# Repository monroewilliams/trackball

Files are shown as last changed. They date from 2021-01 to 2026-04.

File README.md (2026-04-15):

This is the code to run a trackball I'm building for myself.<br>

It's currently based around either a [Seeeduino XIAO](https://wiki.seeedstudio.com/Seeeduino-XIAO/) or the very similar [Adafruit QT Py](https://www.adafruit.com/product/4600), and a couple of optical mouse sensor breakout boards. I've built two so far, one using [these ADNS-9800 boards](https://www.tindie.com/products/jkicklighter/adns-9800-optical-laser-sensor/), and one using [these PMW3360 breakout boards](https://www.tindie.com/products/jkicklighter/pmw3360-motion-sensor/).

### Update January 2025 ###
As an alternative to off-the-shelf microcontrollers and sensor boards, I've created a custom main board and sensor breakouts that can be ordered from a PCB creation/assembly service (I've been using [JLCPCB](https://jlcpcb.com)). The KiCad files and the files need to order them from JLCPCB are in their own repositories on github. 

[Details on the custom boards are here.](hardware/Custom.md)

### Update January 2026 ###
I've refined the model for the main body of the trackball to be less of a brick and more of a hollow shell, which leaves much more room inside for wire routing, etc. The cable outlet at the front of the shell now also provides an option for a hard-mounted [usb-c plug](https://www.sparkfun.com/sparkfun-usb-c-breakout.html), or [similar](https://www.amazon.com/dp/B0CB2VFJ54) [clones](https://www.aliexpress.us/item/3256808121945210.html) 

I added an [updated version of the button carrier](hardware/Button-carrier-v2.md). Its design is a bit more refined overall, but the main feature is that it allows you to avoid soldering wires to the microswitch by accepting a 3-pin JST XH female connector.

I also added an option to modify the sensor transform for a left-handed build. To make use of this, print mirrored versions of the main body and bottom plate (most slicers have an option to do this at slicing time), and define LEFT_HANDED when compiling trackball.cpp to modify the sensor transform. The `env:rp2040_mwtrackball_left_handed` section in [platformio.ini](platformio.ini) demonstrates this.

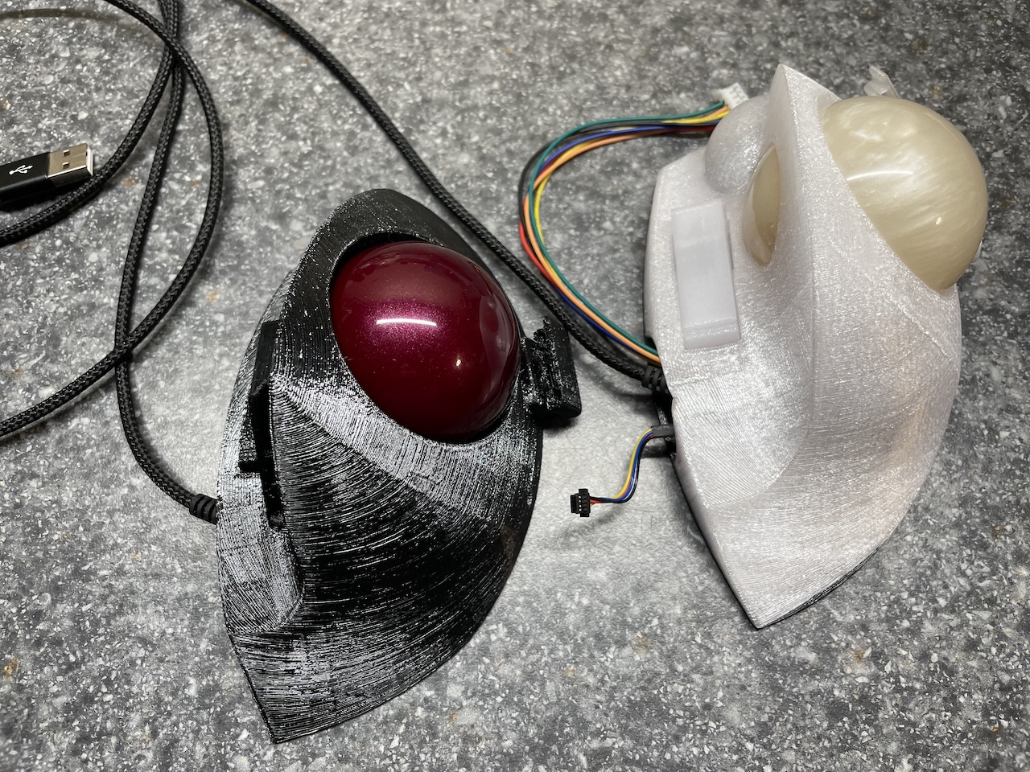
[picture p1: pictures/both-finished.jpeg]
<br>

## History ##

I started this project because my favorite ergonomic trackball, the Trackman Marble FX, is basically no longer viable. I really like the shape of it, but it's PS/2 only, has a number of issues with tracking and durability, and has become really hard to find/expensive. I have a small collection of them, most of which have broken over the years.<br>

I decided to build my own trackball with a shape that fits my hand similar to the old Trackman Marble FX, and incorporated a feature from the Kensington Slimblade (probably my second favorite, although not for its ergonomics): twisting the ball in the Z axis acts like a scroll-wheel (complete with clicky sounds produced by a piezo speaker).<br>

[Short video demo is here](https://www.youtube.com/watch?v=PVdwrbiuzwA)

To be able to sense rotation in all three axes, it needs to use two mouse sensors, positioned at different points around the ball. <br>

I'm quite happy with the current state of the project. I prefer using this trackball to any other I've used at this point, which is saying something. :) <br>

The [hardware](hardware) directory contains the OpenSCAD files for the printed plastics. The [src](src) directory has the code. If you want to see how all the parts fit together, you can go straight to the [assembly guide](hardware/Assembly.md). <br>

## BUILD ##

I'm building this with PlatformIO/VSCode. The root of the repository should open directly with VSCode.

I do my work on Mac OS X, so I don't know if there will be any issues using it on Windows or Linux.

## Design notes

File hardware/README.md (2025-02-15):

# Printables #

This directory contains the [OpenSCAD](https://www.openscad.org) models for the trackball body and microswitch buttons I've designed.

The trackball body model is in `trackball.scad`. There are many parameters that can be tweaked, see the comments in that file for details. 

It's designed using 14mm square holes for the buttons, which should fit either standard Cherry MX (or compatible) keyboard switches or the microswitch-based button I've designed for the project.

The model for the button is in `microswitch-cherry-mx.scad`. The variables at the top set front and rear overhangs, which can match up with cutouts in the trackball body to act as recessed buttons with minimal travel.

If you're thinking about putting one together yourself, take a look at the [assembly guide](Assembly.md).

# Components #

In addition to the 3D printed parts, you will need the following:

## Microcontroller ##

I've used all of the following:

- Seeeduino XIAO microcontroller (although any controller that has a binding for the Arduino library in PlatformIO should be easy to adapt):

https://wiki.seeedstudio.com/Seeeduino-XIAO/

- Adafruit QT Py (it's very similar with the same pinout and processor). It has a couple of niceties over the XIAO, including an actual reset button and an RGB LED that could be used to light things up.

https://www.adafruit.com/product/4600

- Adafruit QT Py RP2040, which is a somewhat more capable processor:

https://www.adafruit.com/product/4900

- [My custom board](./Custom.md), which can be assembled for you by an assembly service like [JLCPCB](https://jlcpcb.com).

## Optical mouse sensors ##

You will need two of these. I originally started this project with ADNS-9800 laser optical mouse sensor breakouts from here:

https://www.tindie.com/products/jkicklighter/adns-9800-optical-laser-sensor/

and have since picked up two PMW3360 optical mouse sensor breakouts from here:

https://www.tindie.com/products/jkicklighter/pmw3360-motion-sensor/

The plastics have options to use either kind (or even one of each), and the code also supports both kinds.

The PMW3389 breakout from the same source should also work.

https://www.tindie.com/products/jkicklighter/pmw3389-motion-sensor/

It seems that this seller is no longer active, but other sellers on Tindie have similar products:

https://www.tindie.com/products/citizenjoe/pmw3360-motion-sensor/

https://www.tindie.com/products/citizenjoe/pmw3389-motion-sensor/

I also have a [custom-designed sensor board](./Custom.md) that pairs well with my custom main board, and can also be ordered from [JLCPCB](https://jlcpcb.com).

## Ball ##

My original prototype used a regulation 2 1/4" (~57mm) billiard ball. The ADNS-9800 sensors I was using at the time really wanted some optical texture to be able to track the ball, and the best one I found was the cue ball from a pearlescent set I bought from eBay just for this project.

The set I bought: https://www.ozonebilliards.com/product/pro-series-kandy-pearl-ball-set

Similar single cue ball: https://www.paramountindustriesinc.com/products/pearlescent-cue-ball

For best results with modern sensors like the PMW3360/3380, I would highly recommend using a 55mm ball specfically designed for an optical trackball. These have a sort of "sparkly" visual texture that works really well with the optical sensors. This ball will fit and work fine in a body printed with a ball diameter of 57mm, but I would recommend bumping ball_diameter down to 55 in trackball.scad for a better fit.

The Kensington Slimblade and Kensington Expert Mouse trackballs use this size, as does the Perixx Periboard combination keyboard/trackball. Perixx sells a compatible replacement ball, which is a good way to get one without buying extra hardware you don't need:

https://www.amazon.com/gp/product/B07DXBMT6Z/

and various sellers on Amazon and AliExpress have similar 55mm replacement balls:

https://www.amazon.com/gp/product/B0CPDG8LX4

https://www.aliexpress.us/item/3256806116943772.html (Careful with this one -- it's easy to order the 34mm ball by mistake.)

## USB Cable ##

You'll neeed a USB-C cable with a relatively small connector. There's not a lot of room under the printed shell for the cable plug.

I've modeled a channel for the cable to run out the front of the body, but I haven't yet found a cable that can plug into the microcontroller and make the turn to get into the channel, which is why the cable currently sticks out the side. I may eventually switch to a processor that has solder-pads for the USB connection, or hack together a cable with a solder-on USB-C plug, but for now I'm using one of these:

https://www.amazon.com/gp/product/B081F1VR6W/

## Breadboard ##

Standard mini breadboard (170 tie point version), available through many sources:

https://www.amazon.com/Breadboard-Solderless-Prototype-Different-Raspberry/dp/B07LF71ZTS/

## Bearings ##

You will need 3 ceramic ball bearings, diameter 1/8 inch (3.175mm), which press-fit into holes in the printed body. 
For smooth operation, I recommend grade G5 or better (lower numbers are smoother, so G10 is worse than G5).
They're cheap in packs of 25 or 50, and I recommend getting some extras because they're really easy to lose.
Either of these will work fine:

https://www.amazon.com/gp/product/B081SNH8J5/

https://www.amazon.com/gp/product/B07ZKPZK8Y/

## Buttons ##

Three Subminiature microswitches, OMRON D2FC-F-7N or equivalent (most of the ones sold as "mouse switches" are an idential form factor, approximately 12.8x5.8x6.5mm, and should fit in the carriers):

https://www.amazon.com/D2F-01F-Switch-Microswitch-Subminiature-Logitech/dp/B0062WNDLI

## Piezo speaker ##

If you want twist-scrolling to make a "click" sound, you'll need one of these. (If you don't want this, just undefine PIN_PIEZO in the trackball source and skip it). These are available from multiple sources, I've used one of these:

https://www.adafruit.com/product/160

and also one of these (after desoldering the wires):

https://www.amazon.com/gp/product/B01MR1A4NV/

## Misc ##

4 - M2 x 6mm machine screws to hold the sensors in place. (I originally used some tiny self-tapping screws I had in my junk parts stash, but have since enlarged the screw holes to fit machine screws -- they should hold fine in PETG as long as you don't over-tighten them.)

Hookup wires, solder, etc. for wiring up the sensors and switches. I used some old ribbon cable for the sensor wiring to keep things tidy. I find that soldering the wires to break-apart male header pins makes for solid plug-in attachement to the breadboard.

Optional: Thin adhesive-backed rubber to make non-skid feet for the bottom of the trackball.  I initially used some leftover sticky-backed rubber from a sheet of rubber feet, and later found this stuff, which works much better:

https://www.amazon.com/gp/product/B0D41RLHJZ

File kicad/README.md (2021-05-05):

# Board

This directory contains the [Kicad](https://kicad.org) files for a circuit board I've designed for the trackball. This is intended to take the place of the breadboard in a more permanent build.<br>

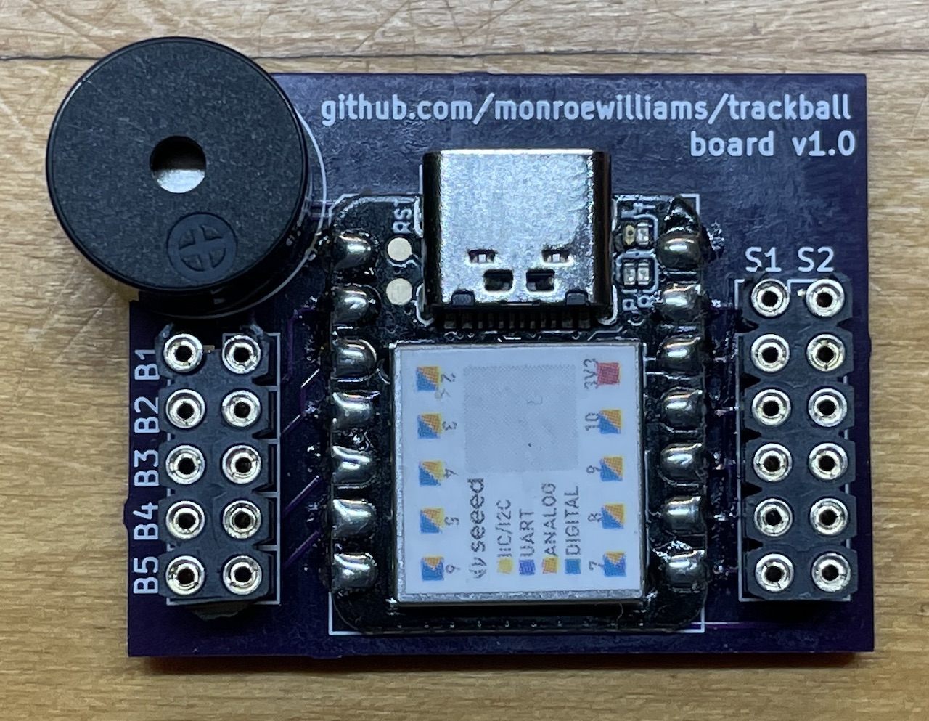
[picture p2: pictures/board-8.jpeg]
<br>

This design uses the [Seeeduino XIAO Kicad library](https://www.seeedstudio.com/blog/2020/04/23/use-seeeduino-xiao-in-kicad-pcb-design-like-a-components/), so if you want to open/modify it with Kicad you probably need to install that first.<br>

This is my first attempt at designing something with Kicad, and I really have no idea what I'm doing. I've had an initial batch of them made by [OshPark](https://oshpark.com), but I haven't actually tested them out yet, so caveat emptor, etc, etc.<br>

I also haven't yet modified the OpenSCAD files for the trackball body to have an option that will make these fit properly. I'm working on that as time allows.<br>

That being said, if you want some of these made for yourself, you can order them 3 at a time [here](https://oshpark.com/shared_projects/D077qVES).<br>

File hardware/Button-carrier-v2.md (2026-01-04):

The updated button carrier prints in two pieces -- the main body, and a cap that holds the microswitch in place.

To use this version, print the `microswitch-v2` stl files instead of the older `microswitch-cherry` ones, insert the microswitch as shown (making sure the switch is oriented with the switch under the projection from the top piece), and snap the cap side in. It should hold the switch tightly when inserted into the square hole in the trackball body.

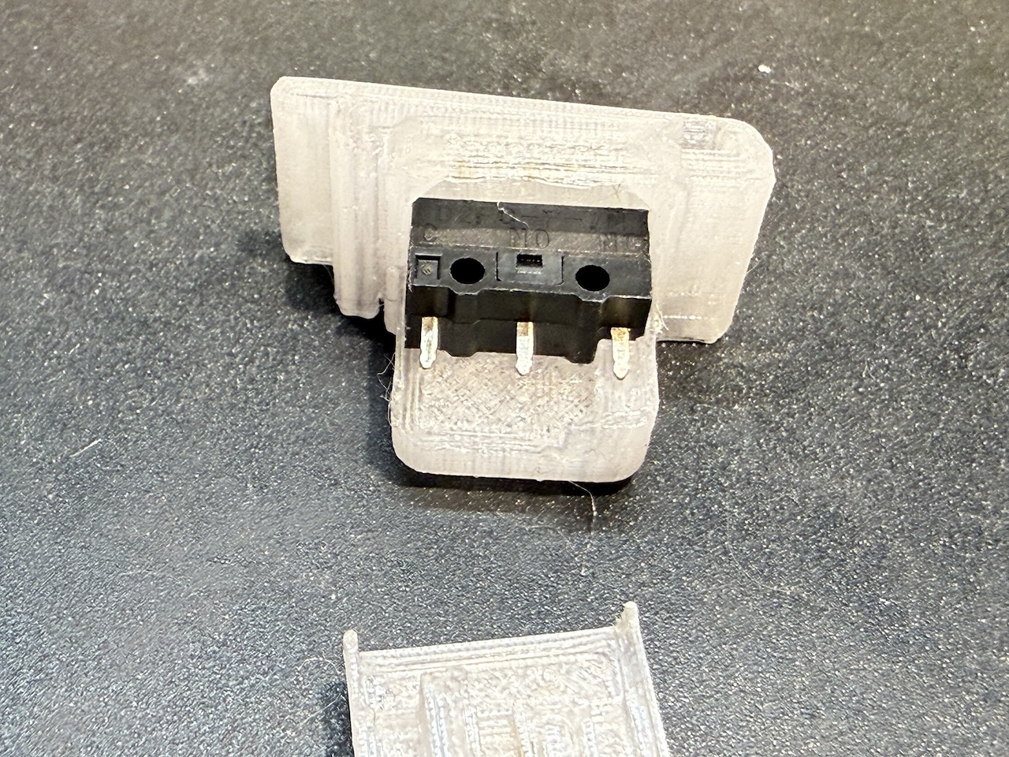
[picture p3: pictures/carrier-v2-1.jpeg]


Insted of soldering wires to the switch, the wiring connection can now be made by inserting a female JST-XH 1.25mm-pitch connector into the back of the carrier. Pins 1 and 3 of the connector will line up with the common and normally-open pins on the microswitch, and the pins on the switch should be close enough to the JST_XH pin profile to make good contact.

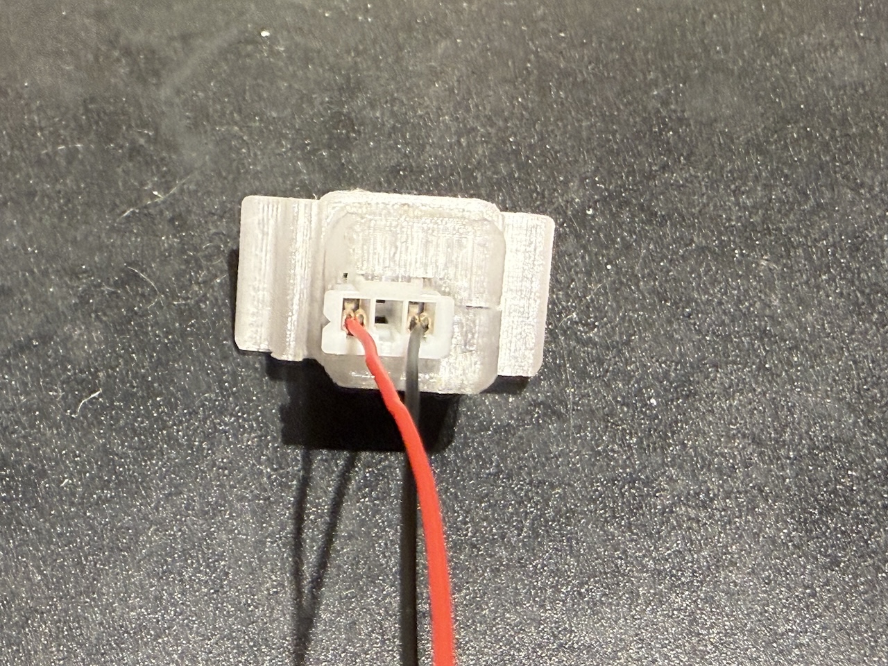
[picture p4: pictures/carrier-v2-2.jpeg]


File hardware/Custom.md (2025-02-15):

# Custom boards #

I recently designed a custom sensor board and main board for use with this trackball design. The primary motivations behind this were:
- more reliable and permanent builds than the original breadboard method
- easier assembly (allowing the use of off-the-shelf cables for the sensors instead of soldering my own)

To this end, both the sensors and the main board use very compact JST-SH 1.0mm pitch connectors (6 pin for the SPI sensors and 2 pin for the buttons). The pinout for the SPI connections on both the mainboard and the sensors is taken from [Pmod Type 2](https://en.wikipedia.org/wiki/Pmod_Interface).

## Sensor breakout ##

My custom sensor board is in [this github repository](https://github.com/monroewilliams/pmw3360-breakout).

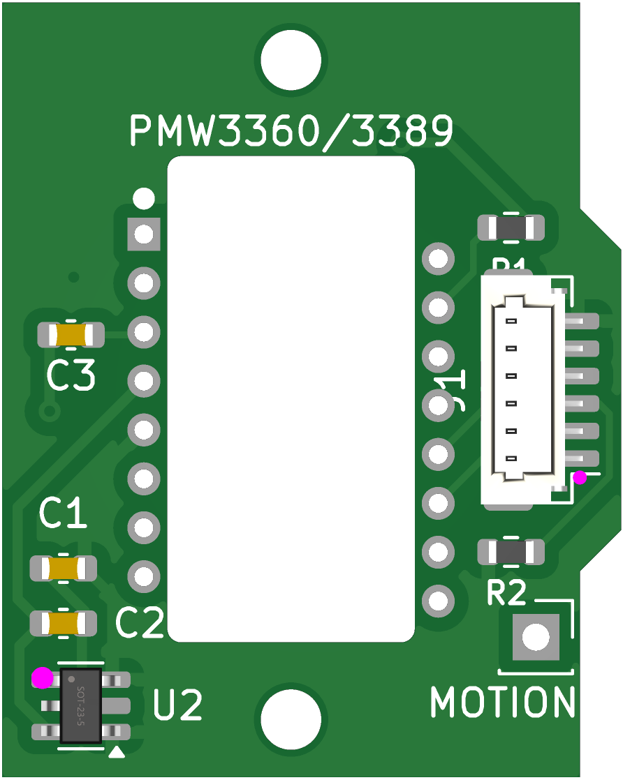
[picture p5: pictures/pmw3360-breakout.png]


It's derived from [jfedor2](https://github.com/jfedor2)'s [PMW3360 breakout board](https://github.com/jfedor2/pmw3360-breakout) project, modified to use a footprint very similar to the PMW3360 breakout boards I sourced from sellers on Tindie, and with a surface mount JST-SH 6 pin connector instead of 2.54mm pitch through-hole pads.

As with his project, there are no level shifters on this board, so it must be used with 3.3v logic. 

The assembly service doesn't seem to be able to place the actual sensor, so I source those separately and hand-solder them (they're through-hole at around 1.75mm pitch, so not too difficult). The board works equally well with PMW3360 and PMW3389 sensors (the pinouts are compatible). Both sensors can be found on AliExpress for under $10USD each, just make sure you order ones that have the "LM19-LSI" lens included, like [this one](https://www.aliexpress.us/item/3256807282468640.html).

## Main board ##

The main board is in [this github repository](https://github.com/monroewilliams/rp2040_mwtrackball).

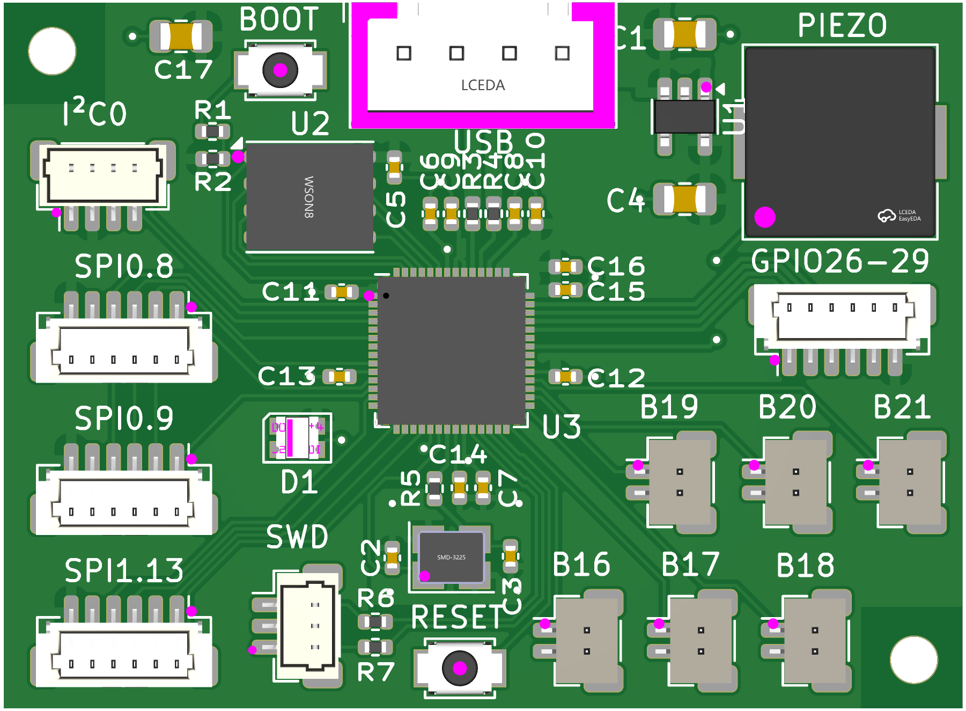
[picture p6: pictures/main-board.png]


It uses an RP2040 processor, and is derived from the sample [minimal reference design](https://datasheets.raspberrypi.com/rp2040/Minimal-KiCAD.zip) provided by Raspberry Pi.

Features include:
- 2 JST-SH 6 pin connectors connected to SPI0, with distinct chip-select lines
- 1 JST-SH 6 pin connector connected to SPI1, with its own chip-select line
- 6 JST-SH 2 pin connectors each connected to a GPIO (16 through 21) and ground, for easy connection to button switches
- 1 JST-SH 4 pin connector connected to I2C-capable pins, and compatible with Qt-STEMMA plugs
- 1 JST-SH 3 pin connector following the [Raspberry Pi 3-pin Debug Connector Specification](https://datasheets.raspberrypi.com/debug/debug-connector-specification.pdf)
- 1 JST-SH 6 pin connector breaking out some of the remaining GPIOs (26 through 29), as well as +3.3v and ground
- USB broken out on a 4 pin JST-XH header.
- an on-board surface mount piezo speaker
- a NeoPixel LED (because why not?)

For the basic trackball design, all that's needed is two of the SPI connections and 3 buttons (give or take), but if I was going to the trouble of designing a board I wanted to give it a bit of room to grow. 

The overall dimensions of the board (46mm x 34mm) are approximately the same as those of the mini-breadboard I used in the original project. This means it will fit in the existing plastics design without any modifications. (Although if you're replacing the electronics in an existing build like I did, the new sensor boards may need a bit more clearance. A hand file is your friend here.)

This repository has a variants directory containing a [pins_arduino.h](../variants/rp2040_mwtrackball/pins_arduino.h) describing the board, and there's an `[env:rp2040_mwtrackball]` section in the [platformio.ini](../platformio.ini) showing how to use it. This is the configuration I'm currently using for my own trackball, so I can say with some confidence that it works.

## Cables, etc. ##

I was able to source all the cables I needed for assembly pretty cheaply from AliExpress. 

Both types of JST-SH cables I used are from [here](https://www.aliexpress.us/item/3256807031812901.html) 
- "6P, 100mm, Reverse" for the SPI cables
- "2P, 100mm, Single head" for the pigtail cables to connect the button switches (I just hand-soldered these to the switch contacts)

The USB cable [here](https://www.aliexpress.us/item/3256806154142780.html) ("XH2.54-4P 1M") has the correct pinout to plug directly into the JST-XH USB header.

## Assembled ##

These are pictures of a board from the second prototype run, before I added the SWD plug. The first batch of "version 1.0" boards is in production as I write this.

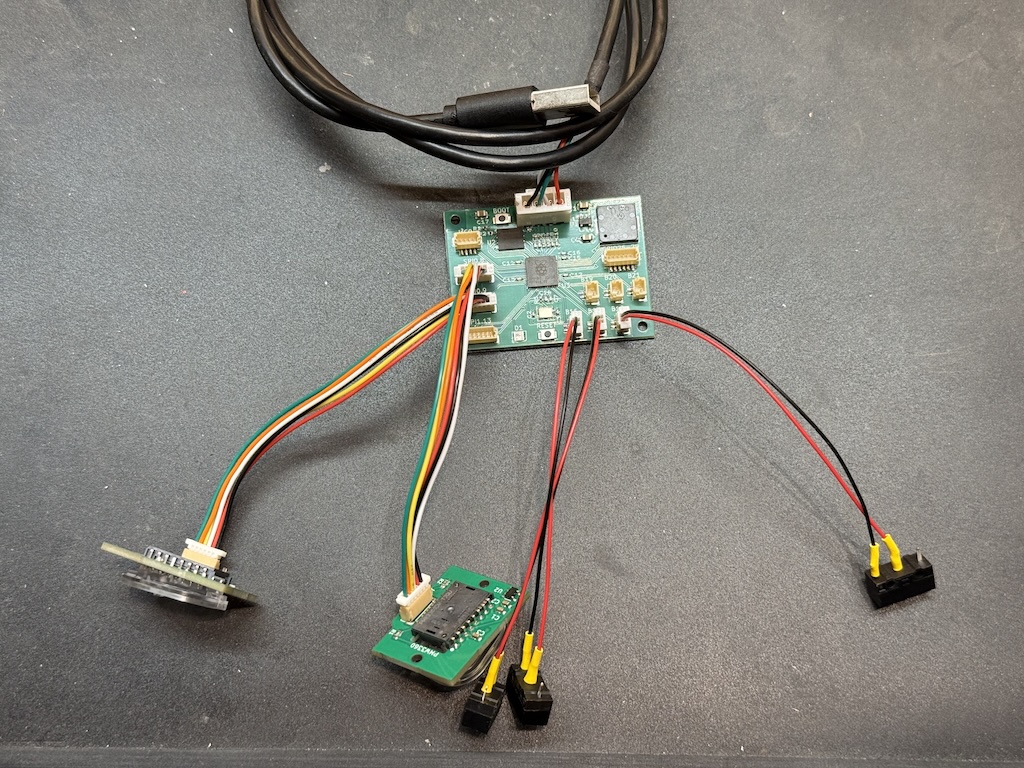
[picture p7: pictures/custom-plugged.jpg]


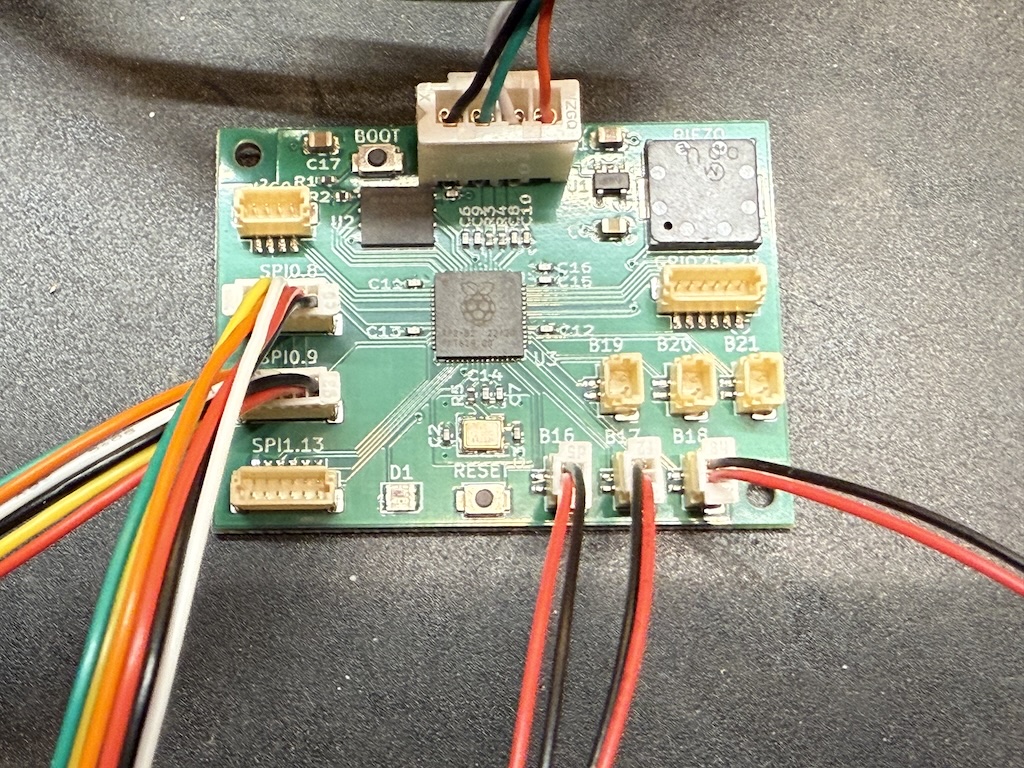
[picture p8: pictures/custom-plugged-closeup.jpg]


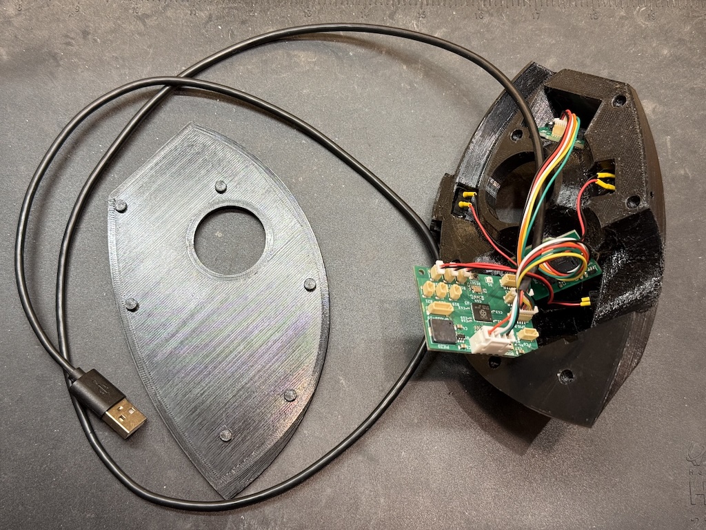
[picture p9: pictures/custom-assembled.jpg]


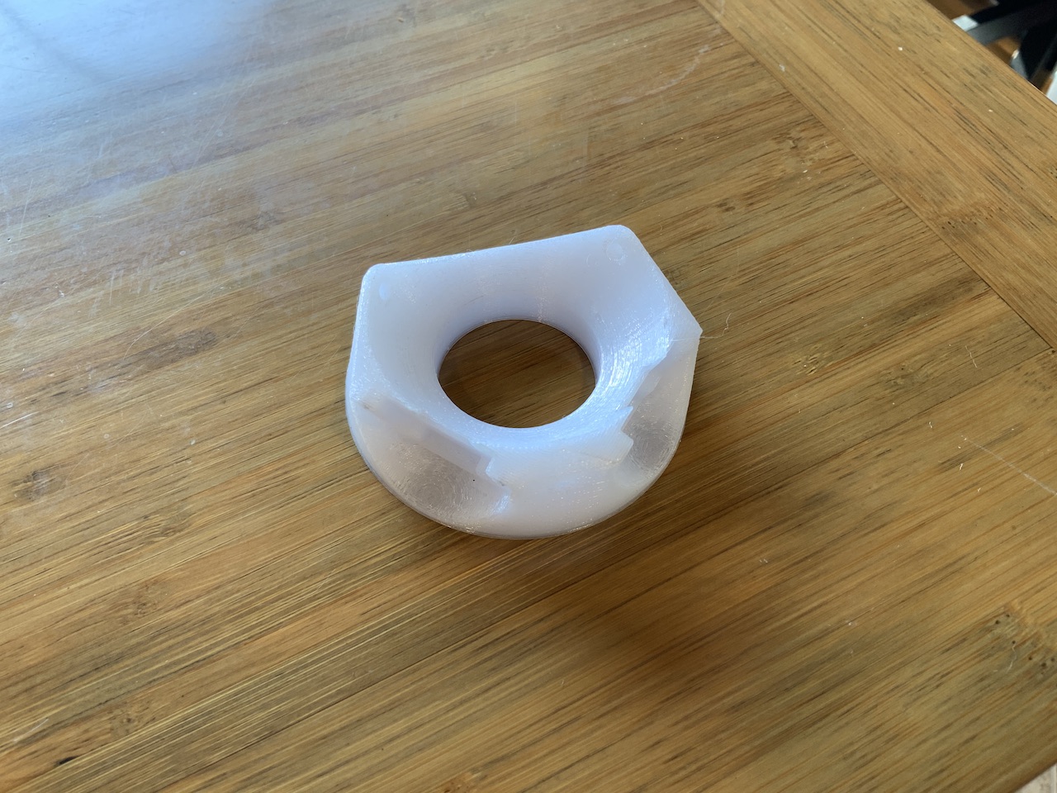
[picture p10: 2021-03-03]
pictures/prototype-2.jpeg

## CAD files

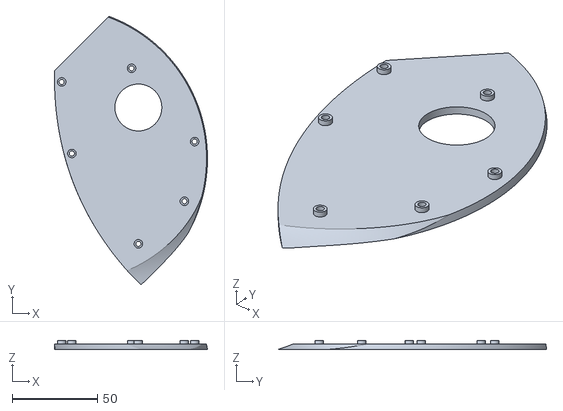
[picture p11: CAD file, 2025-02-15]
stl/bottom_cover_3mm-52.5mm.stl
89.8 x 157.4 x 5.00

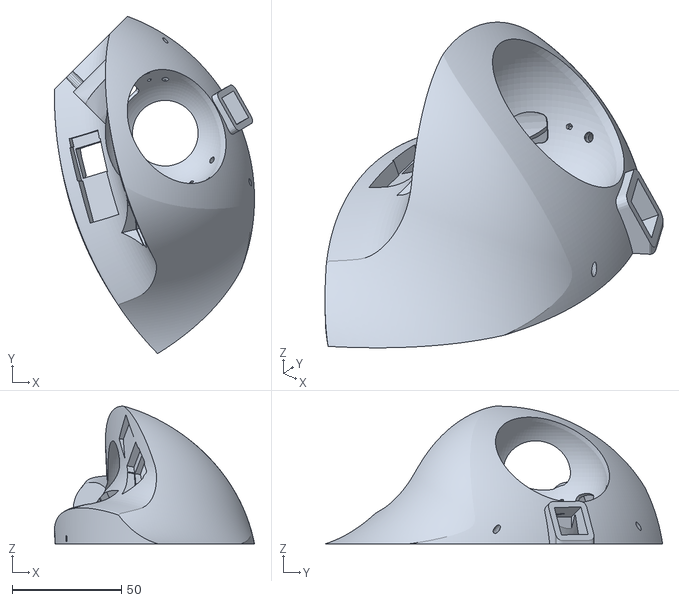
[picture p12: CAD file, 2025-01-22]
stl/trackball-55mm-pmw3360-hollow.stl
91.4 x 154.2 x 62.9

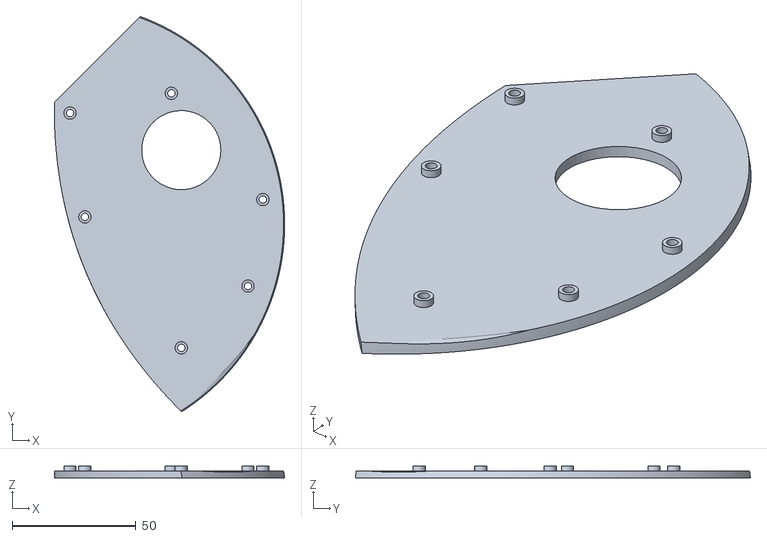
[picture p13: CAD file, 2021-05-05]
stl/bottom_cover_3mm-57mm.stl
93.2 x 159.8 x 5.00

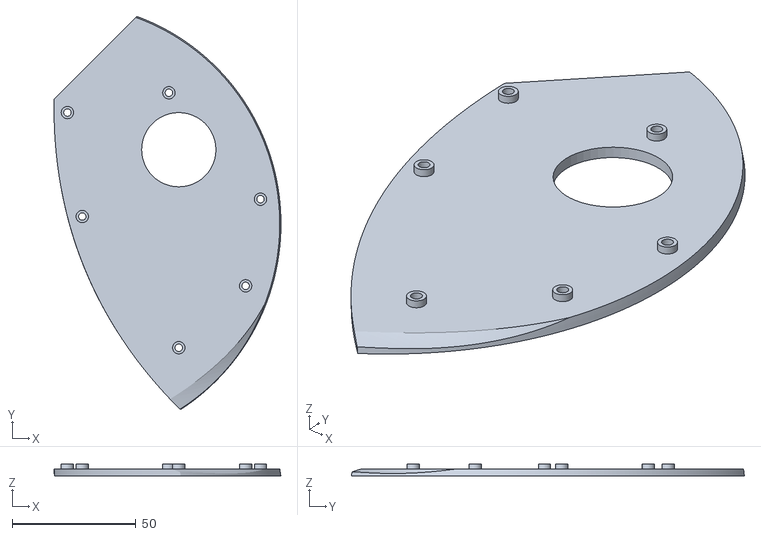
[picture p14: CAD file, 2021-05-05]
stl/bottom_cover_3mm-55mm.stl
91.7 x 158.8 x 5.00

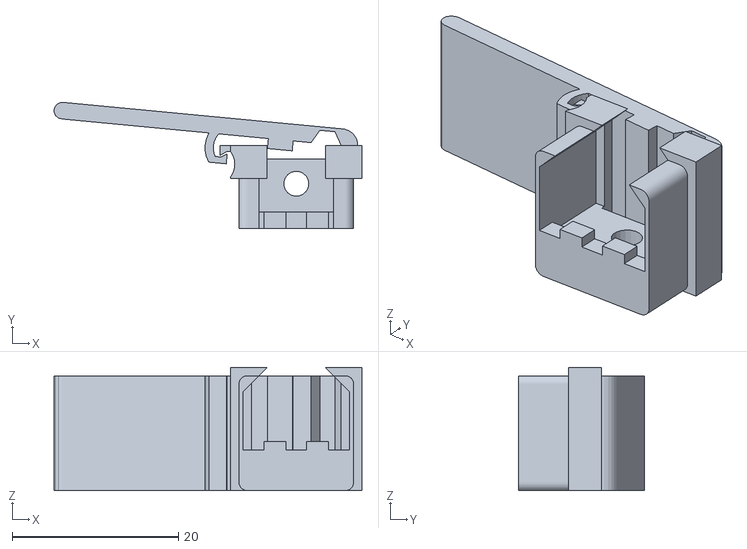
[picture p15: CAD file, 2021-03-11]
stl/microswitch-cherry-mx-20-0.stl
37.0 x 15.2 x 14.8

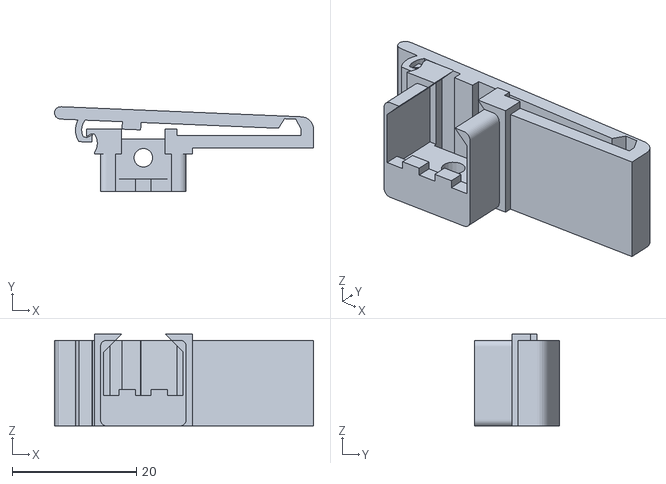
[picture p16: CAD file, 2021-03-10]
stl/microswitch-cherry-mx-5-20.stl
41.7 x 13.6 x 14.8

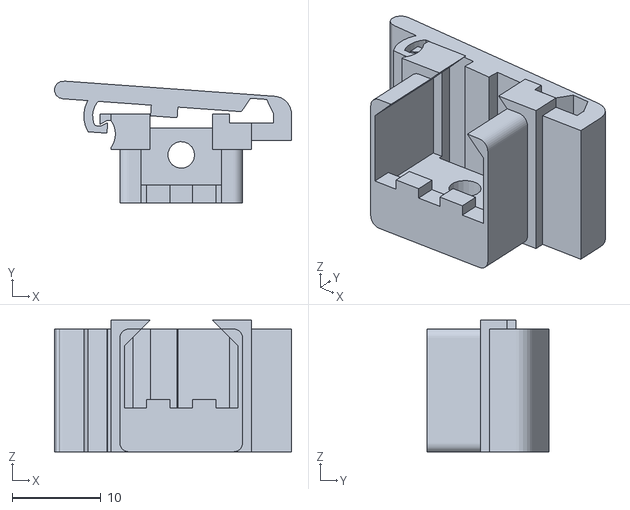
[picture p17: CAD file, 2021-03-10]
stl/microswitch-cherry-mx-5-5.stl
26.7 x 13.7 x 14.8

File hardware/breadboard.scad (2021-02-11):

use <trackball.scad>
// Breadboard cutout test

difference()
{
    // Uncomment this to make a hollow shell with the breadboard cutout inside
    // minkowski()
    // {
    //     breadboard_cutout();
    //     intersection()
    //     {
    //         $fn = 15;
    //         sphere(r=1);
    //         ccube(10, 10, 10);
    //     }
    // }

    breadboard_cutout();
}

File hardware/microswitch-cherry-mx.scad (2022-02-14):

// Examples
switch_carrier(20, 0);

translate([0, -20, 0]) 
switch_carrier(5, 20);

translate([0, -40, 0]) 
switch_carrier(5, 5);

module switch_carrier(front_overhang = 0, rear_overhang = 0)
{
    // front_overhang and rear_overhang extend the top surface on the end opposite the hinge, and the end with the hinge, respectively.

    // This makes a cutout that leaves room to plug a 3-position JST-XH connector onto the
    // two "normally open" pins of the switch.
    connector_space = false;

    // Outer size of the main body of the adapter. Note that "height" is a bit of a misnomer,
    // as the top deck extends well beyond this.
    // The width may need fine adjustment based on your printer and the size of the hole you're
    // fitting the switch into. This setting works well for my printer, when using a hole that
    // I've modeled as exactly 14x14mm.
    body_width = 13.8;
    body_height = 10;

    // Dimensions of the microswitch. I'm using OMRON D2FC-F-7N switches.
    // Note that these dimensions are likely to be finicky and dependent on the accuracy of your printer.
    switch_length = 12.8;
    switch_width = 6;
    switch_height = 6.8;

    // This is the thickness of the top over the hinge cut. I recommend tweaking this to make your
    // slicer lay this down as a single line for flexibility. When slicing with Cura, if I make it
    // too thin that part of the model actually gets omitted, and if I make it too thick it gets
    // messy as well.
    hinge_thickness = 0.18;

    top_thickness = 2;
    top_safety = front_overhang >= 1;

    $fs=0.5;

    switch_bottom_height = body_height - (switch_height + 1.2);
    switch_centering = (body_width - switch_length) / 2;
    top_rotation_base = switch_centering + switch_length - 1;

    // Test cube to help me see where the rotation point of the top is
    //translate([top_rotation_base + rear_overhang, body_height, 5])
    //cube([10, 10, 10]);

    // Length of the top, not counting rounded ends
    top_length = body_width + front_overhang + rear_overhang;
    // Final X offset the top will be shifted by
    top_offset =  switch_centering - front_overhang - 2;

    // distance from the left edge of the switch to the center of the contact
    contact_offset = 4.5;
    // space we want to leave under the contact at rest
    contact_space = 1.5;
    // Calculate a top angle that will leave enough space under the center of the contact at rest.
    contact_distance = (top_rotation_base + rear_overhang) - (switch_centering + 4.5);
    top_angle =  atan(contact_space/(rear_overhang + body_width + top_thickness));

    module switch_cutout()
    {
        difference()
        {
            translate([0, 0, 0])
            {
                // main switch body
                translate([0, switch_bottom_height, 0])
                cube([switch_length, switch_height, body_width]);
                // top clearance
                translate([1, switch_bottom_height + switch_height - 0.4, -body_width])
                cube([switch_length - 2, 3.0, body_width * 2]);
                // pushout hole
                translate([
                    switch_length / 2, 
                    switch_bottom_height + switch_height / 2, 
                    -body_width
                ])    
                cylinder(d=3, h=body_width * 2);
                
                translate([0, -1, 0])
                {
                    translate([0, 0, 1])
                    {
                        // Cutouts for contacts
                        cube([2.5, 5, 13]);
                        translate([switch_length - 2.5, 0, 0])
                        cube([2.5, 5, 13]);
                        translate([(switch_length - 2.5) / 2, 0, 0])
                        cube([2.5, 5, 13]);
                    }

                    // The bottom supports don't need to extend past the center of the switch.
                    translate([2, 0, (switch_width / 2) - 1])
                    cube([9, 5, body_width - 1]);
                    
                }
            }
            // chamfer the inside corners, but leave room to get the switch out past the supports.
            translate([0, 0, switch_width + ((switch_width / 2) - 1)])
            {
                rotate([0, -45, 0])
                cube([5, body_height, 5]);

                translate([switch_length, 0, 0])
                rotate([0, -45, 0])
                cube([5, body_height, 5]);
            }
        }
        
    }

    module body()
    {
        difference()
        {
            union()
            {
                // main body
                // Instead of this, give the body slightly rounded outside corners.
                // cube([body_width, body_height, body_width]);
                rotate([-90, 0, 0])
                translate([0, -body_width, 0])
                linear_extrude(body_height)
                offset(1, $fn=32) offset(delta=-1)
                square(body_width, body_width);
            
                // lip
                difference()
                {
                    translate([-1, 6, 0])
                    cube([body_width + 2, body_height - 6, body_width + 1]);

                    if (top_safety)
                    {
                        translate([-3, body_height - 2.25, 0])
                        cylinder(d=5, h=body_width + 1, $fn=32);
                    }
                }
                
                // Extension for hinge
                if (rear_overhang > 0)
                {
                    translate([top_rotation_base + top_thickness, body_height - 3, 0])
                    cube([rear_overhang, 3, body_width]);
                }
                
                // body side of safety catch
                if (top_safety)
                {
                    translate([-2.25, body_height - .75, 0])
                    {
                        cube([2.25, .75, body_width]);
                        translate([.25, 0, 0])
                        cylinder(d=1, h=body_width, $fn=3);
                    }
                }
            }
            // cut for clearance on extended hinge
            if (rear_overhang > 0)
            {
                translate([top_rotation_base, body_height - 1, 0])
                cube([rear_overhang, 1, body_width + 1]);
            }
            
            if (connector_space)
            {
                translate([0, 0, 1.0 + (body_width - switch_width)/2])
                cube([8.5, switch_bottom_height, body_width + 1]);
            }
        }

    }

    module top()
    {
        translate([0, body_height, 0])
        translate([top_offset, 0, 0])
        translate([top_length, 0, 0]) rotate([0, 0, -top_angle]) translate([-top_length, 0, 0])
        {
            {
                difference()
                {
                    union()
                    {
                        // main top surface
                        cube([top_length, top_thickness, body_width]);

                        // Rounded free end
                        translate([0, top_thickness / 2, 0])
                        cylinder(d=top_thickness, h=body_width);

                        // Rounded hinge end
                        translate([top_length, 0, 0])
                        cylinder(r=top_thickness, h=body_width);

                    }
                    
                    // cut bottom half of hinge end round
                    translate([top_length - top_thickness, -top_thickness, 0])
                    cube([top_thickness * 2, top_thickness, body_width]);
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

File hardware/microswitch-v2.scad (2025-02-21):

include <BOSL2/std.scad>


// Examples
//switch_carrier(20, 0, 14);
//
//switch_carrier(5, 20, 14);
//
//switch_carrier(5, 5);

$fa = 1;
$fs = 0.01;


module switch_carrier(front_overhang = 0, rear_overhang = 0, body_height = 14, bridge = true, split = true, hinge = false)
{
    // front_overhang and rear_overhang extend the top surface on the end opposite the hinge, and the end with the hinge, respectively.

    // This makes a cutout that leaves room to plug a 3-position JST-XH connector onto the
    // two "normally open" pins of the switch.
    connector_space = true;

        
    // Dimensions of the microswitch. I'm using OMRON D2FC-F-7N switches.
    // Note that these dimensions are likely to be finicky and dependent on the accuracy of your printer.
    switch_length = 13;
    switch_width = 6;
    switch_height = 6.8;

    // This is the thickness of the top over the hinge cut. I recommend tweaking this to make your
    // slicer lay this down as a single line for flexibility. When slicing with Cura, if I make it
    // too thin that part of the model actually gets omitted, and if I make it too thick it gets
    // messy as well.
    hinge_thickness = 0.4;

    // Outer size of the main body of the adapter. Note that "height" is a bit of a misnomer,
    // as the top deck extends well beyond this.
    // The width may need fine adjustment based on your printer and the size of the hole you're
    // fitting the switch into. This setting works well for my printer, when using a hole that
    // I've modeled as exactly 14x14mm.
    body_width = 13.8;
    
    // Reduce the overall width of the body slightly in one direction, to make for an easier fit.
    body_clearance = 0.4;

    switch_centering = (body_width - switch_length) / 2;

    top_thickness = 2;
    top_safety = front_overhang >= 1;

//    $fs=0.5;

    top_rotation_base = switch_centering + switch_length - 1;

    // Test cube to help me see where the rotation point of the top is
    //translate([top_rotation_base + rear_overhang, body_height, 5])
    //cube([10, 10, 10]);

    // Length of the top, not counting rounded ends
    top_length = body_width + front_overhang + rear_overhang;
    // Final X offset the top will be shifted by
    top_offset =  switch_centering - front_overhang - 2;

    // distance from the left edge of the switch to the center of the contact
    contact_offset = 4.5;
    // space we want to leave under the contact at rest
    contact_space = 1.5;
    // Calculate a top angle that will leave enough space under the center of the contact at rest.
    contact_distance = (top_rotation_base + rear_overhang) - (switch_centering + 4.5);
    top_angle =  atan(contact_space/(rear_overhang + body_width + top_thickness));

    module microswitch_cut()
    {
        difference()
        {
            union()
            {
                // Main switch body
                cuboid([switch_length, switch_height, switch_width], anchor = FRONT);
                
                // clearance for pins
                for (i = [-5, 0, 5 ])
                translate([i, 0, 0])
                cuboid([2, 5, switch_width / 6], anchor = BACK);
                
                // the button itself
                color("red")
                translate([4.5 -(switch_length/2), switch_height, 0])
                rotate([0, 0, 90])
                cylinder(d = 1, h = 3, center = true);
                
            }
            union()
            {
                // nubs that fit the holes in the switch
                r = 1.3 / 2;
                for (z = [-switch_width/2, switch_width/2])
                for (x = [-2.7, 2.7])
                translate([x, 1.0 + r, z])
                {
                    sphere(r = r - 0.1);
                }
            }
        }
    }

    module sh_xt_3p_cut()
    {
        translate([(8.5 - switch_length) / 2, 0,  4 - (switch_width / 2)])
        {
            cuboid([8.5, 10, 4], anchor = BACK + TOP);
            
            // cuts for the key
            translate([-3.5 / 2, 0, 0])
            cube([1.75, 10, 1], anchor = BACK + BOTTOM + RIGHT);
            translate([3.5 / 2, 0, 0])
            cube([1.75, 10, 1], anchor = BACK + BOTTOM + LEFT);
            translate([0, -10, 0])
            cube([1.75 + 3 + 1.75, 3, 1], anchor = FRONT + BOTTOM);
        }
    }

    
    module switch_cutout()
    {
        difference()
        {
            translate([0, 0, 0])
            {
                // clearance above the switch button
                translate([0, switch_height - 0.4, 0])
                cuboid([switch_length - 2, 3.0, body_width - 4], anchor = FRONT,
                chamfer = 1.4, edges = "Y");
                
                if (!bridge)
                {
                    cube([switch_length, switch_height, body_width]);
                }
                
                // pushout hole
                translate([0, switch_height / 2, 0])    
                cyl(d=3, h=body_width, anchor = TOP);

                // This includes the switch body, but also the contact cutouts
                microswitch_cut();
                
                // Cut above the switch body, but only on the top piece
                translate([0, 4, switch_width - 2])
                cuboid([switch_length, switch_height - 4, switch_width], anchor = FRONT,
                    chamfer = 2, edges = "Y", except = BOTTOM);
                
            }
            // chamfer the inside corners, but leave room to get the switch out past the supports.
//            translate([0, 0, switch_width + ((switch_width / 2) - 1)])
//            {
//                translate([-switch_length/2, 0, 0])
//                rotate([0, -45, 0])
//                cube([5, body_height, 5]);
//
//                translate([switch_length/2, 0, 0])
//                rotate([0, -45, 0])
//                cube([5, body_height - 1, 5]);
//            }
        }
        
    }

    module body()
    {
        body_offset = [-body_width/2, - body_height + (switch_height + 1.2), -body_width/2];
        difference()
        {
            union()
            {
                // main body
                translate(body_offset - [0, 0, 0])
                cuboid([body_width, body_height, body_width - body_clearance], anchor = [-1, -1, -1],
                    rounding = 2, except = BACK);
            
                // lip
                translate(body_offset)
                difference()
                {
                    translate([-1, body_height - 4, 0])
//                    cube([body_width + 2, 4, body_width + 1]);
                    cuboid([body_width + 2, 4, body_width + 1], anchor = [-1, -1, -1],
                        rounding = 2, edges = "Y");

                    if (top_safety)
                    {
                        translate([-3, body_height - 2.25, 0])
                        cylinder(d=5.25, h=body_width + 1);
                    }
                }
                
                // Extension for hinge
                if (rear_overhang > 0)
                {
                    translate(body_offset)
                    translate([top_rotation_base + top_thickness, body_height, 0])
                    cuboid([rear_overhang, 3, body_width], anchor = [-1, 1, -1],
                        rounding = top_thickness/2, 
                        edges = [TOP+RIGHT, BOTTOM+RIGHT, RIGHT+FRONT]);
                }
                
                // body side of safety catch
                if (top_safety)
                {
                    translate(body_offset)
                    translate([-2.25, body_height - .75, 0])
                    {
                        cube([2.25, .75, body_width]);
                        translate([.25, 0, 0])
                        cylinder(d=1, h=body_width, $fn=3);
                    }
                }
            }
            union()
            {
                // cut for clearance on extended hinge
                translate(body_offset)
                if (rear_overhang > 0)
                {
                    translate([top_rotation_base + 1, body_height, 0])
                    cuboid([rear_overhang - 1, 1, body_width + 1], anchor = [-1, 1, -1]);
                }
                
                if (connector_space)
                {
                    sh_xt_3p_cut();
                }
            }
        }

//        translate([(body_width - switch_length)/2, 5, (body_width - switch_width)/2])
//        sh_xt_3p_cut();

    }
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

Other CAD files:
hardware/trackball-hollow.scad
hardware/test-base.scad
hardware/test.scad
hardware/trackball.scad
stl/bottom_cover_3mm-52.5mm.scad
stl/bottom_cover_3mm-55mm.scad
stl/bottom_cover_3mm-57mm.scad
stl/deprecated/trackball-55mm-pmw3360-custom-board.scad
stl/deprecated/trackball-55mm-pmw3360-skew0-button3mk2.scad
stl/deprecated/trackball-57mm-adns9800-skew10-button3mk2.scad
stl/deprecated/trackball-57mm-pmw3360-skew0-button3mk2.scad
stl/microswitch-cherry-mx-20-0.scad
stl/microswitch-cherry-mx-5-20.scad
stl/microswitch-cherry-mx-5-5.scad
stl/microswitch-v2-20-0-14.scad
stl/microswitch-v2-5-20-14.scad
stl/microswitch-v2-5-5-14.scad
stl/trackball-52.5mm-pmw3360-hollow.scad
stl/trackball-55mm-pmw3360-hollow.scad
stl/trackball-57mm-pmw3360-hollow.scad

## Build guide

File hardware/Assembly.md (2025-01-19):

# Assembly #

This document assumes you are comfortable with 3D printing OpenSCAD models, soldering, and assembling electronics.

There are a number of pre-rendered STL files in the [stl directory](../stl). If those suit your needs, you can skip the whole OpenSCAD step here and drop them into your favorite slicer.

Set up the model in `trackball.scad` by setting `ball_diameter` to the diameter of the ball you want to use, and the entries in `sensor_params` to the type of sensor you're using. (You can also tweak the location/number of button cutouts by modifying the contents of `button_params`, although getting a layout that works can take some tweaking. I would advise trying out the default setup first.)

NOTE: The trackball model is relatively complex, and older versions of OpenSCAD can take a long time (minutes) to render it. If you're doing any work with the model itself, I highly recommend getting a version of OpenSCAD that has the new [Manifold backend](https://www.reddit.com/r/openscad/comments/11usd6v/manifold_backend_is_just_merged/), enabling that, disabling "Automatic Reload and Preview" in the "Design" menu, and just using "Render" in place of "Preview". The Manifold backend is several orders of magnitude faster (yes, really!), and is much, much faster than the preview renderer for this model; with Manifold enabled, the model renders in milliseconds.

Once you're happy with the setup, render it to an STL file with OpenSCAD, open it in your favorite slicer (I use Cura, but any capable slicer will do), slice it, and print it out.

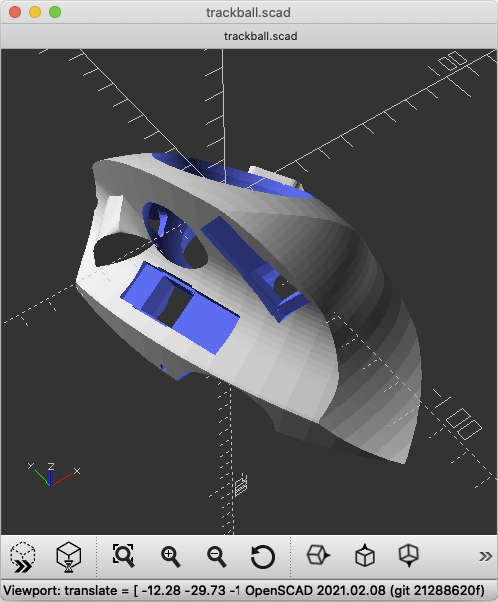
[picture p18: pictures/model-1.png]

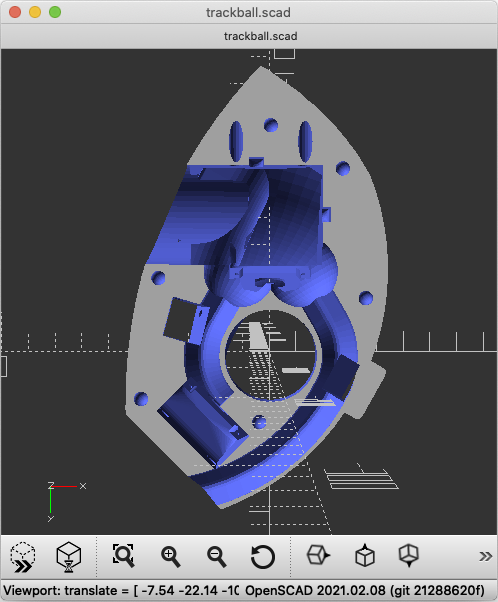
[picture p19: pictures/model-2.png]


If you're using the microswitch buttons, you'll also need three copies of the model from microswitch-cherry-mx.scad, with appropriate tweaks to `top_extra_overhang`/`top_extra_hinge`. (I'm currently using values of 5/20 for the main button, 5/5 for the right button, and 15/0 for the third button.)<br>
**Update March 12, 2021:** I've refined the third button mount a bit. The mount is now lower-profile than what's in these pictures, and it takes a 20/0 carrier instead of a 15/0. This is called out in `trackball.scad` as `"second thumb button, mk. 2"`.<br>

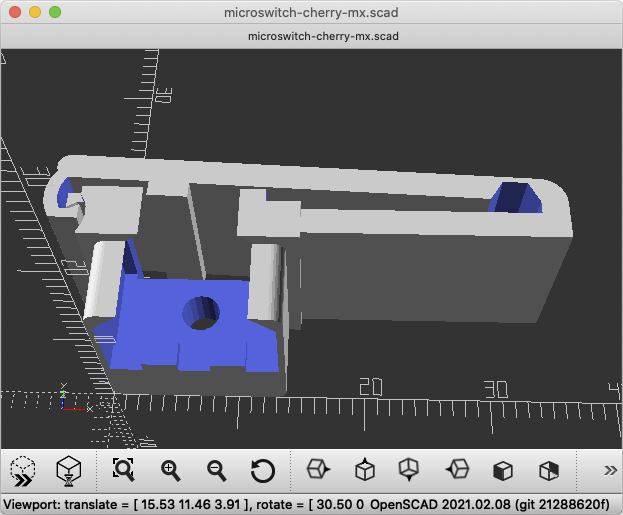
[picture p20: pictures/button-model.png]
<br>

I've designed both the trackball model and the microswitch buttons to print with no supports and require only minimal bridging. You will need a printer with decent dimensional accuracy, as there are a couple of places where tolerances are fairly tight.<br>

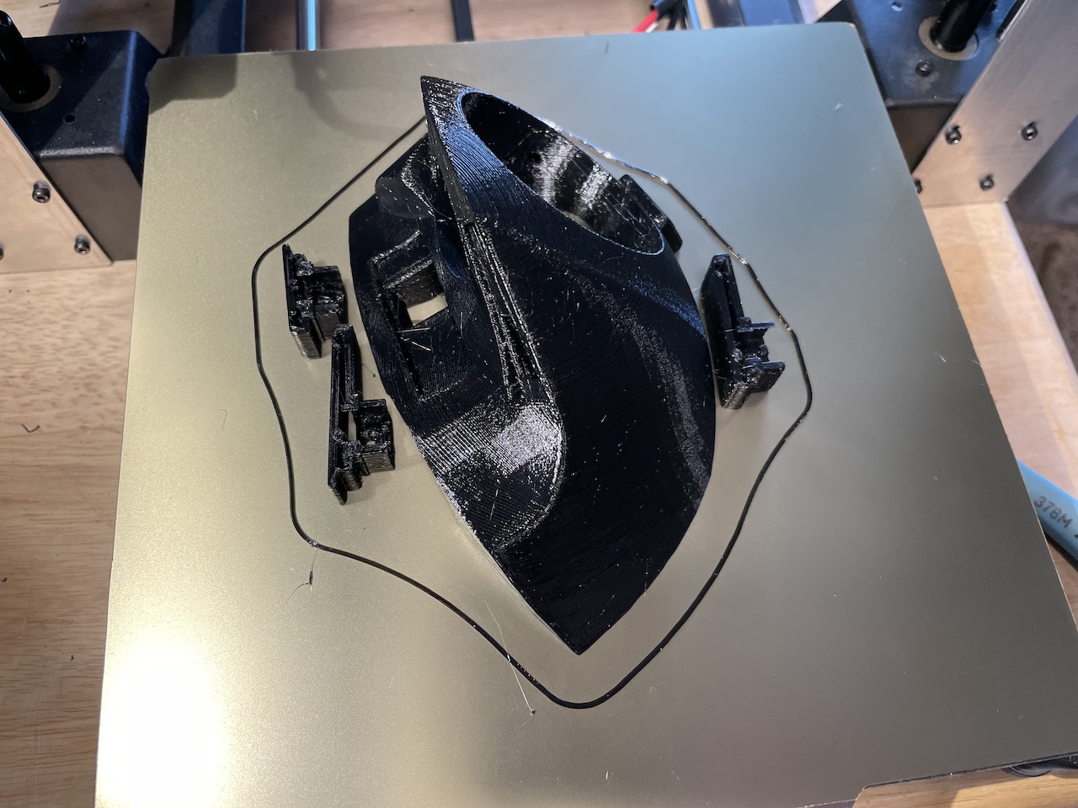
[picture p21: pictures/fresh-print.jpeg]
<br>

The 1/8" bearings press-fit into the three holes around the inside of the ball recess. The little bearings are hard to keep hold of, so make sure you're somewhere that you can find them if they escape. (Shag carpet is not great for this. Ask me how I know...) <br>

It takes a bit of pressure to seat them. I recommend doing them one at a time - hold the body so that the bearing hole faces up, place the bearing carefully onto the hole, and then put the ball on top of it and press down on the ball to seat it. <br>

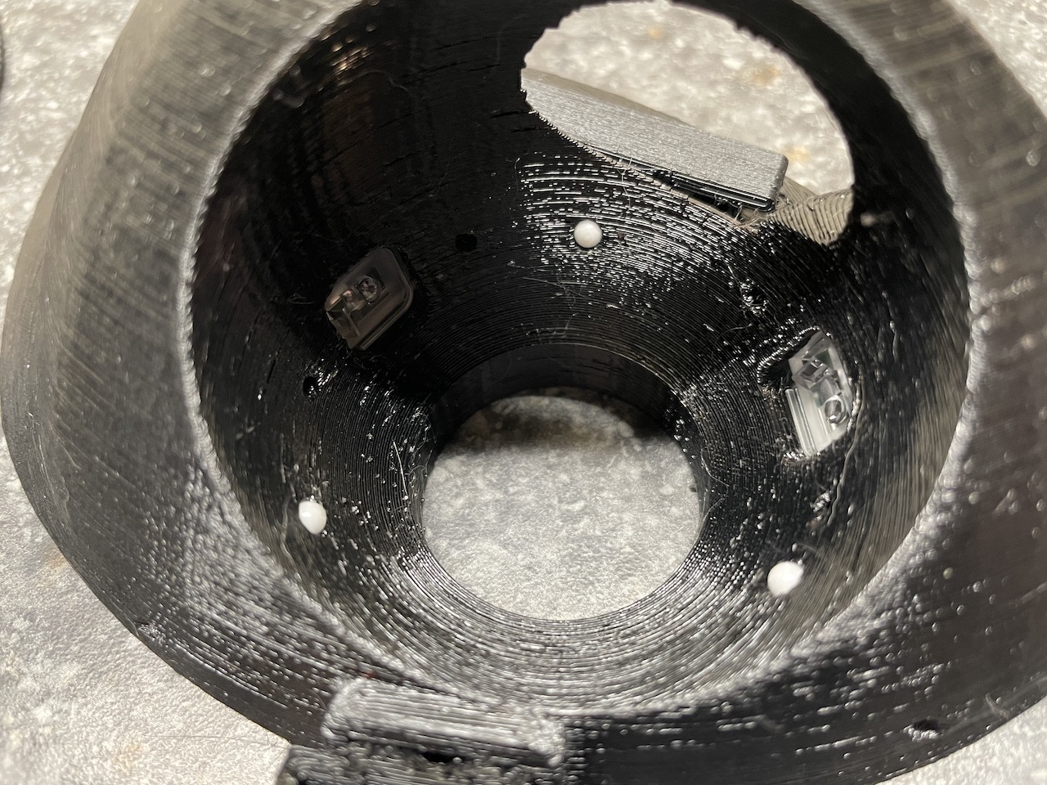
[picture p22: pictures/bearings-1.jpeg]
<br>

If you need to remove the bearings (maybe to move them to a better version of the body), the model has press-out holes that let you push them out from the back. A stiff wire or ~1.5mm allen wrench should fit right through. You'll have to remove the main button to get the one on the left.<br>

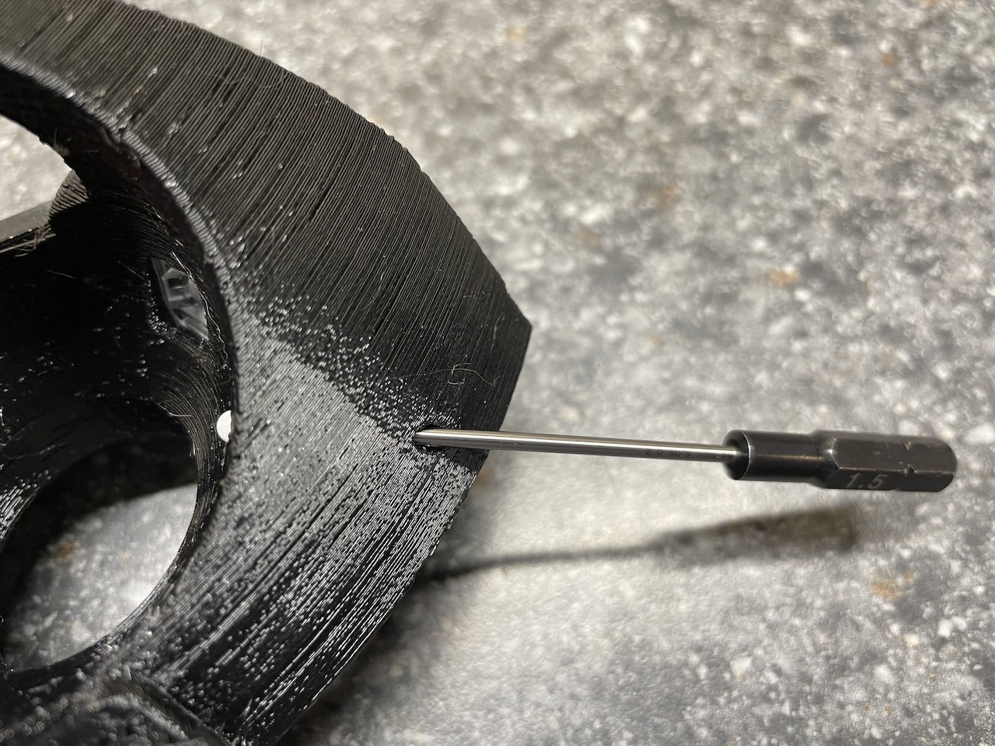
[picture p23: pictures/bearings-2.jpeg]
<br>
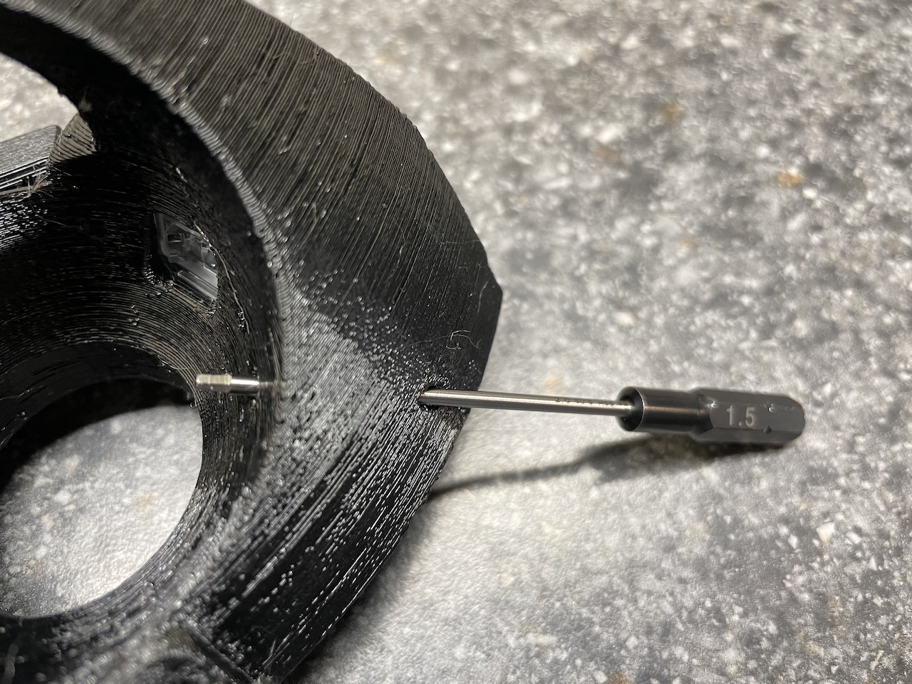
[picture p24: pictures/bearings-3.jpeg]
<br>

Solder wires to the switches and sensors. I like to use break-apart male header pins on the breadboard end of the wires, as they make nice, low-profile plugs that hold well in the breadboard.<br>

Alternately you could skip the breadboard and solder everything onto a piece of perf-board or perma-proto (if you're the sort of person who does crossword puzzles in pen ;) ).<br>

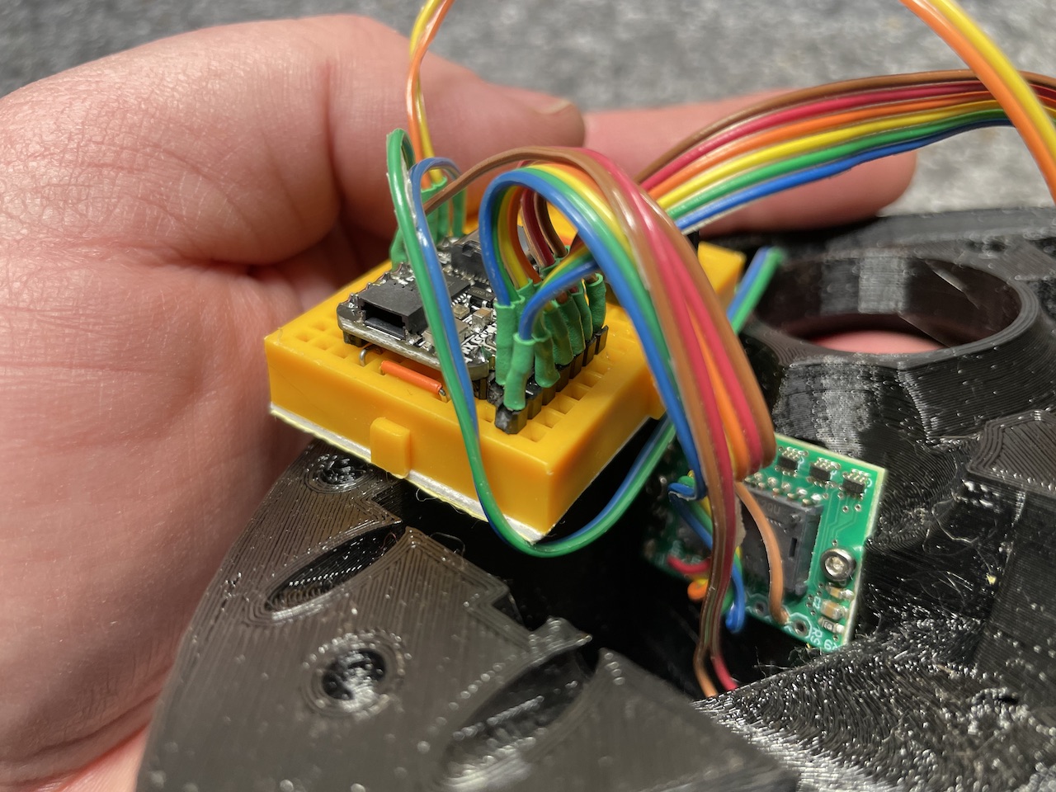
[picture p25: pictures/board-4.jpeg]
<br>

For the sensors, I use 6-conductor ribbon cable, and solder the breadboard end of the wires onto a strip of header pins. I arrange the wires so that they match up with the ordering of the ground, power, and SPI pins that are all together on one side of the XIAO, with the Chip Select wire at the end adjacent to the clock pin. For sensor 1 this gets plugged into the breadboard adjacent to the XIAO and uses the D7 pin for chip-select, and for sensor 2 I leave an empty space (actually making it a 7 pin connector with one missing pin), and bring D6 across from the other side of the breadboard to put it on the next row over. 


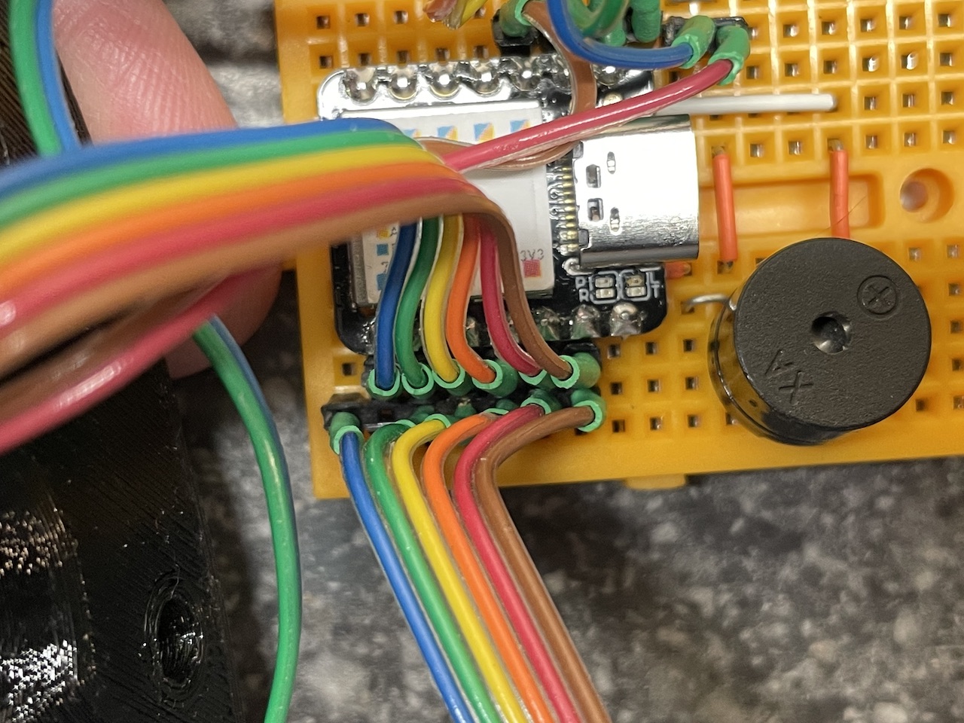
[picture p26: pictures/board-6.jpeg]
<br>

The wires for the buttons connect to A0/A1/A2 on the opposite side of the chip, and the piezo speaker runs to A3 via breadboard wires. My layout has three rows of grounds on the breadboard just past A0 to make it easy to plug in the other end of the switch harnesses, but you could get away with one or two rows if you crowd them a bit.<br>

This leaves A4/A5 (the i2c pins) open if you want to [hook up a display and see the images from the sensors](https://youtu.be/j6Hdsi4Or-g) (see the `SENSOR_DISPLAY` define in trackball.cpp for more info on this).<br>

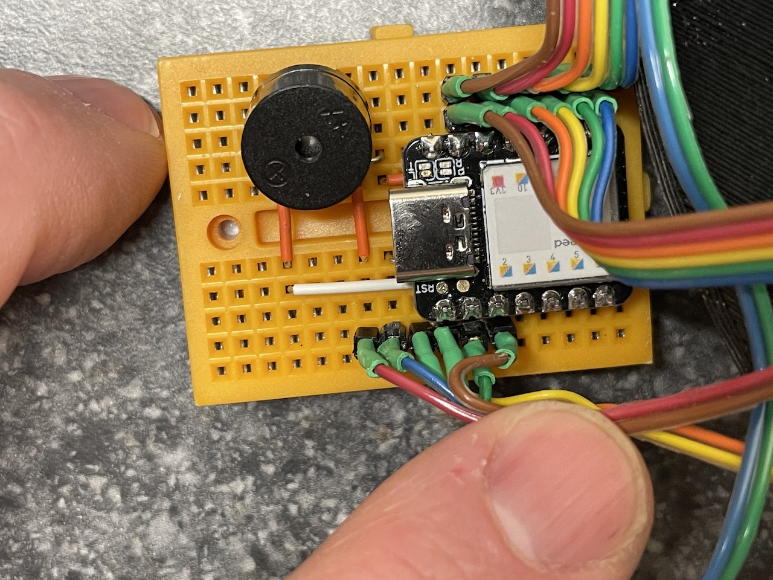
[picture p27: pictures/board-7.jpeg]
<br>

Here are a few more shots of the board layout:<br>

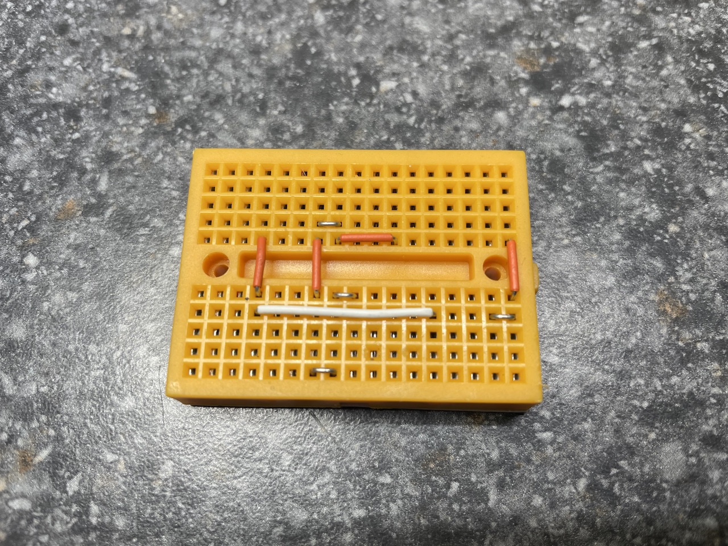
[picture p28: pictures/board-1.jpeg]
<br>
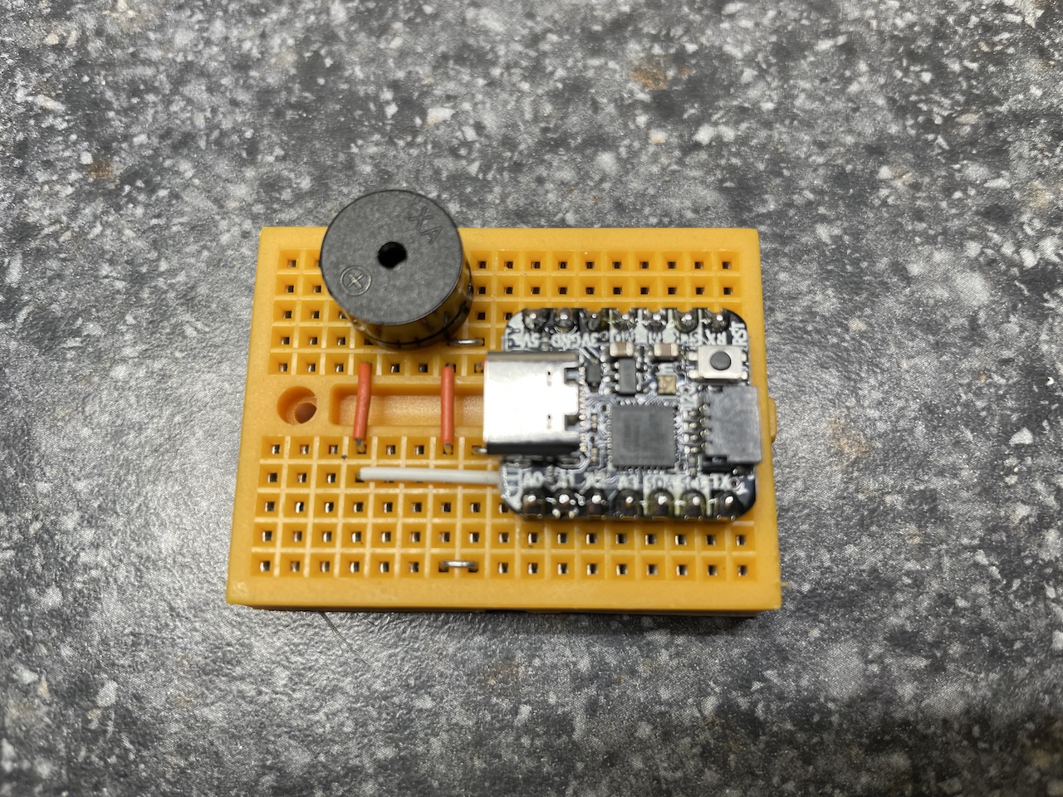
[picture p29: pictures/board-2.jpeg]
<br>
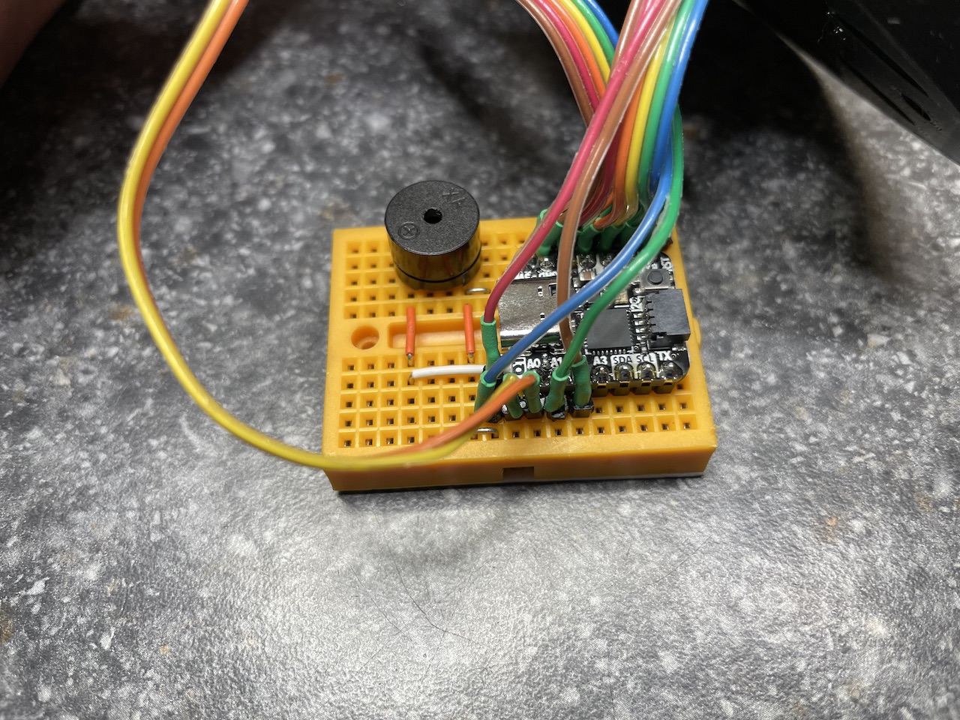
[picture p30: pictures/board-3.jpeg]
<br>
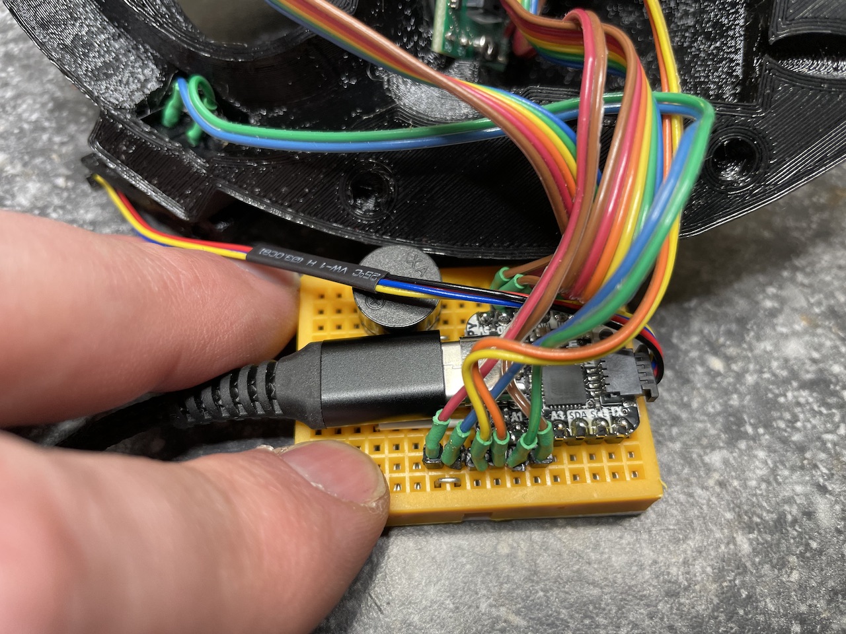
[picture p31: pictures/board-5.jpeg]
<br>

The sensors mount in the cutouts designed for them with 2mm machine screws. The length of the screws isn't critical, but they need to be short enough that they don't stick out and contact the ball.<br>

There are access holes for a screwdriver in-line with each screw hole, and cutouts that allow you to insert the sensor from the bottom of the body. It can be a bit of a dexterity challenge to get all the pieces lined up (especially with the loose lens on the pnw3360), but once the screws catch it should come together.<br>

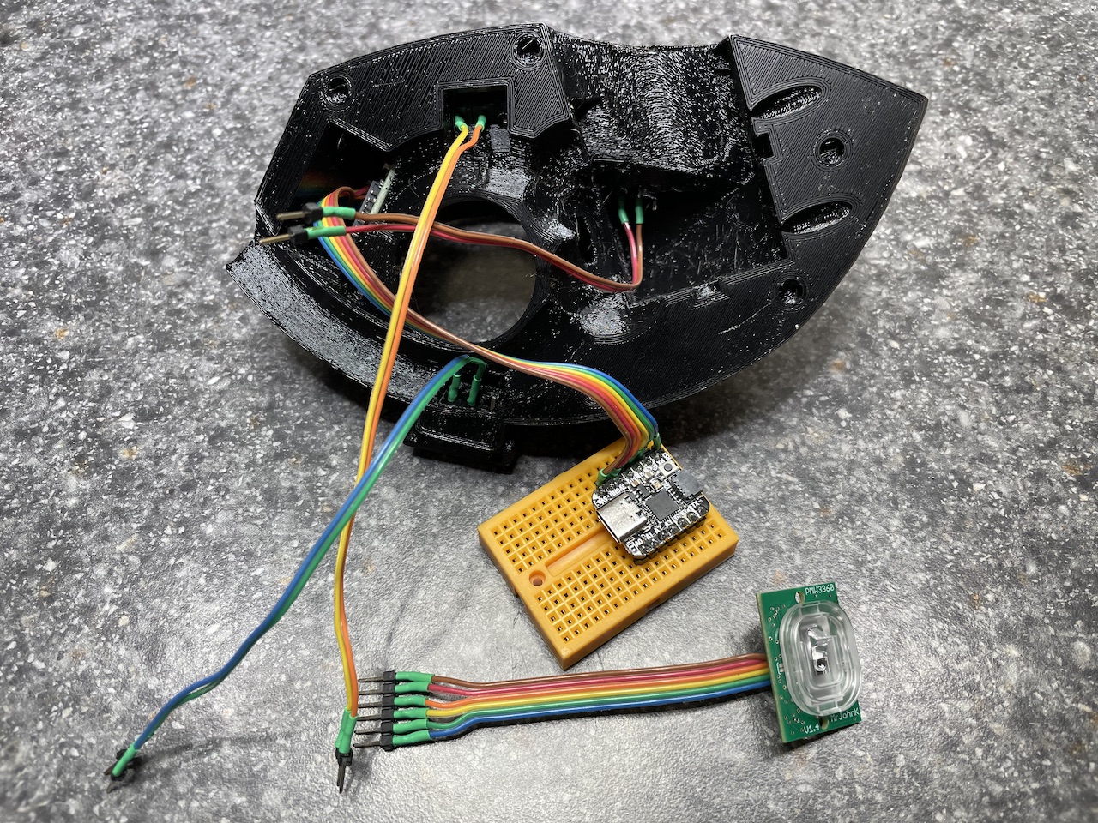
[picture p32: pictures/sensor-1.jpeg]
<br>
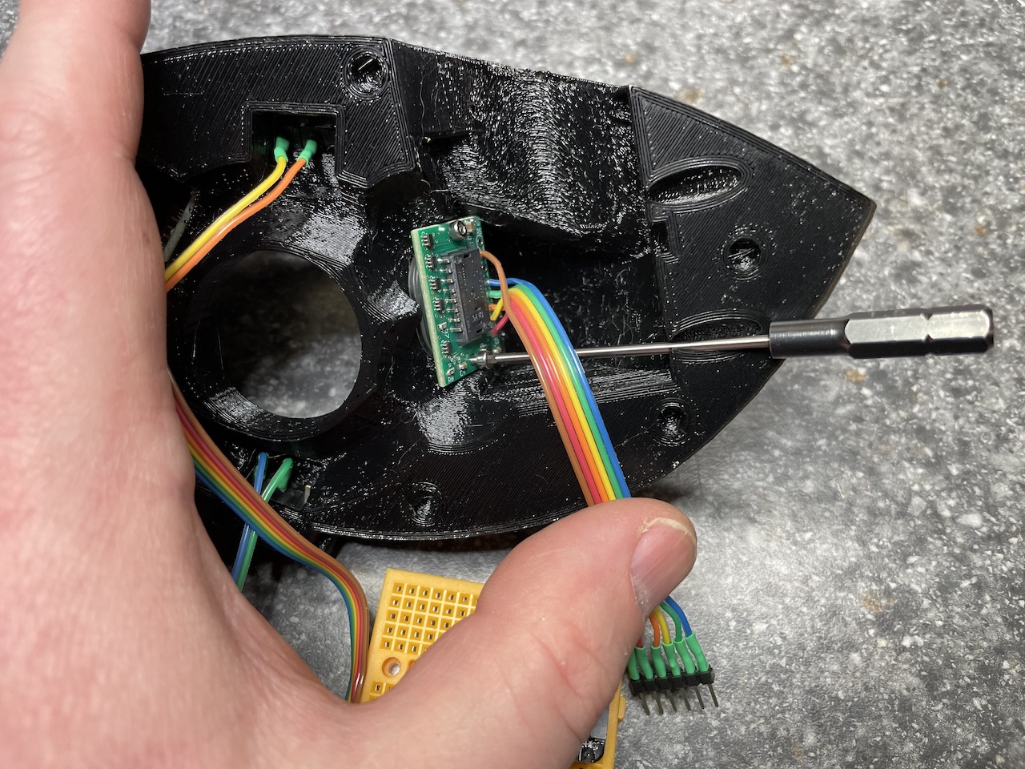
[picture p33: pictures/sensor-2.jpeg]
<br>

The microswitch buttons are set up so that you insert the microswitch from the bottom and slide it sideways to approximately the middle of the switch. Check the orientation of the switch and make sure the switch part is under the bit that sticks down from the top -- if it's the other way around it won't do much. <br>

Once the switch is installed it should have a satisfying mouse-like "click" when you press the top down.  Make sure you click it a few dozen times before continuing. (Yes, this is a mandatory part of the assembly process.) <br>

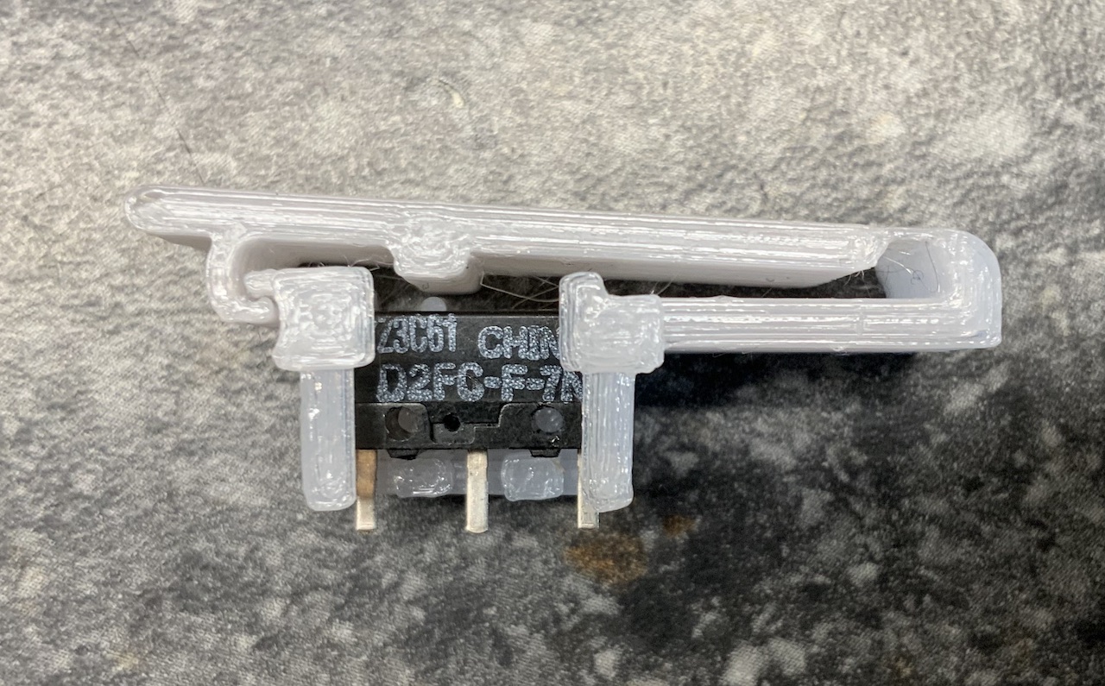
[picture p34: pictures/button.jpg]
<br>
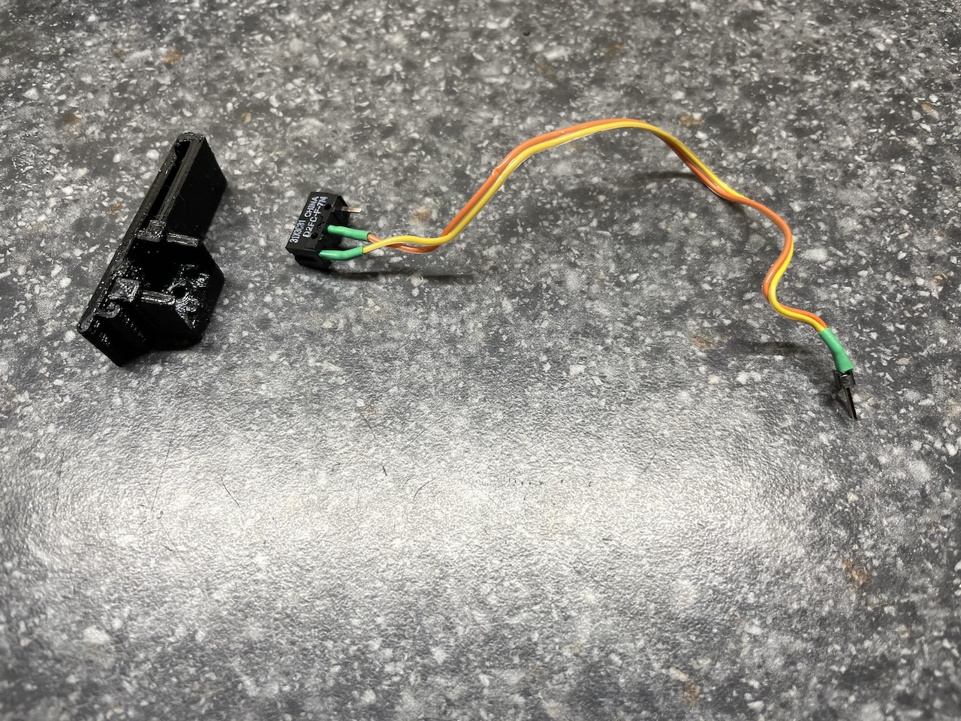
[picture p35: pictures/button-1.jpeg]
<br>
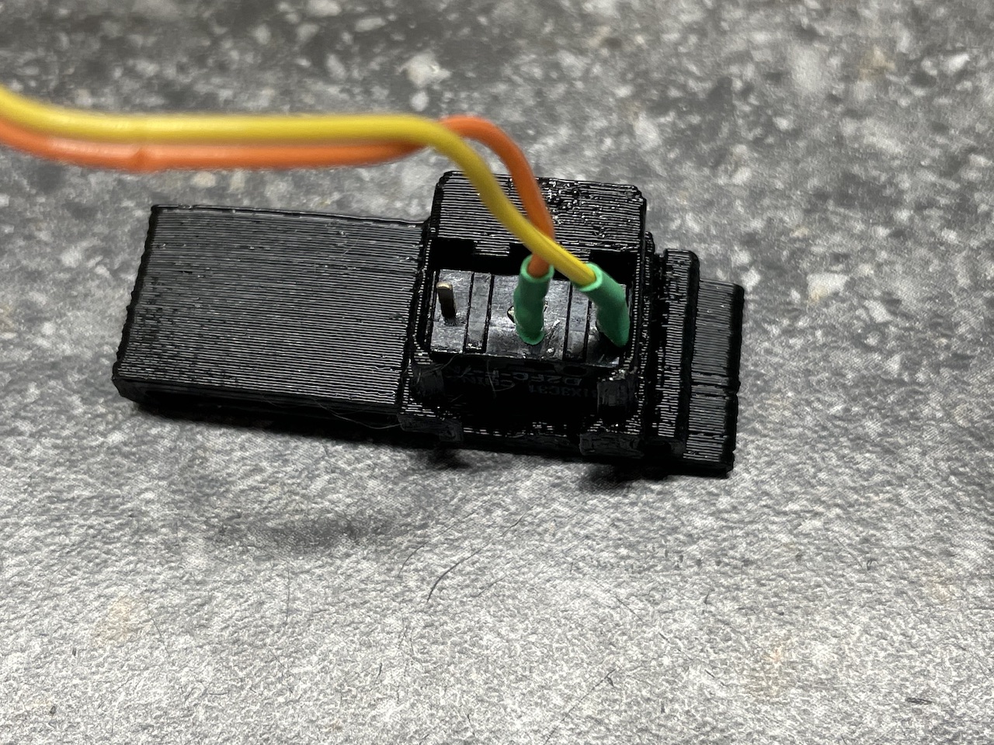
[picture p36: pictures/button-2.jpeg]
<br>
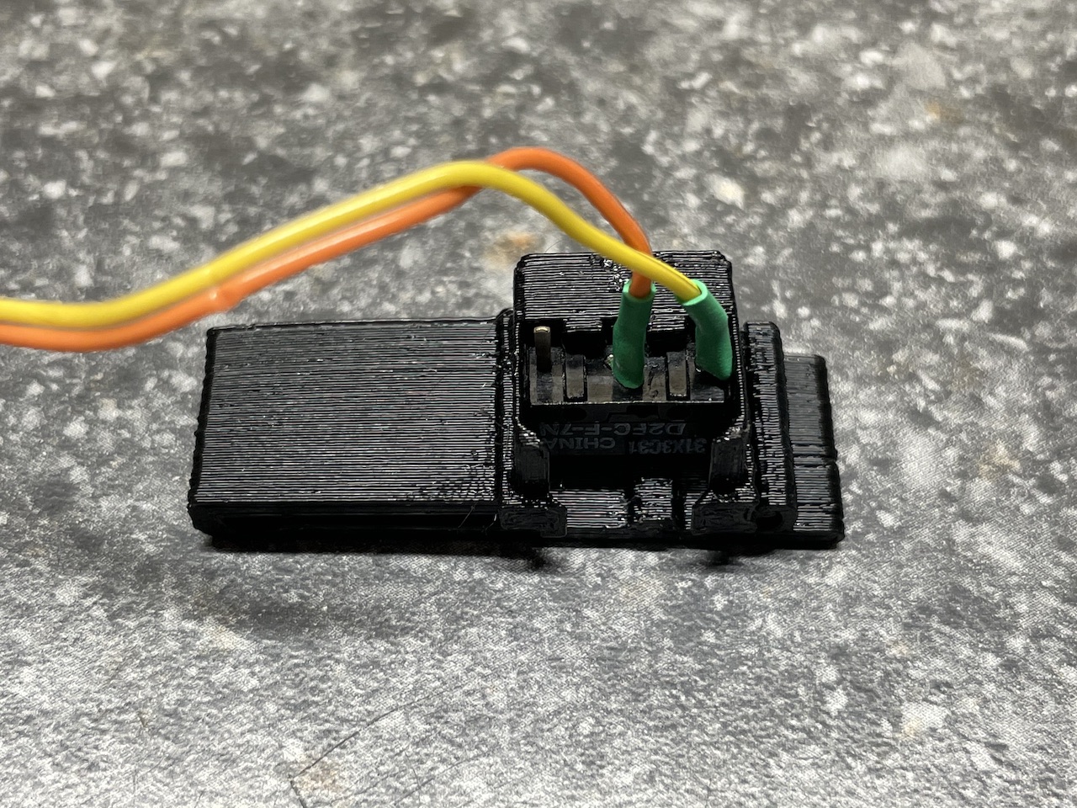
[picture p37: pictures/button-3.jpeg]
<br>

The button assembies press-fit into the square holes in the body.<br> 

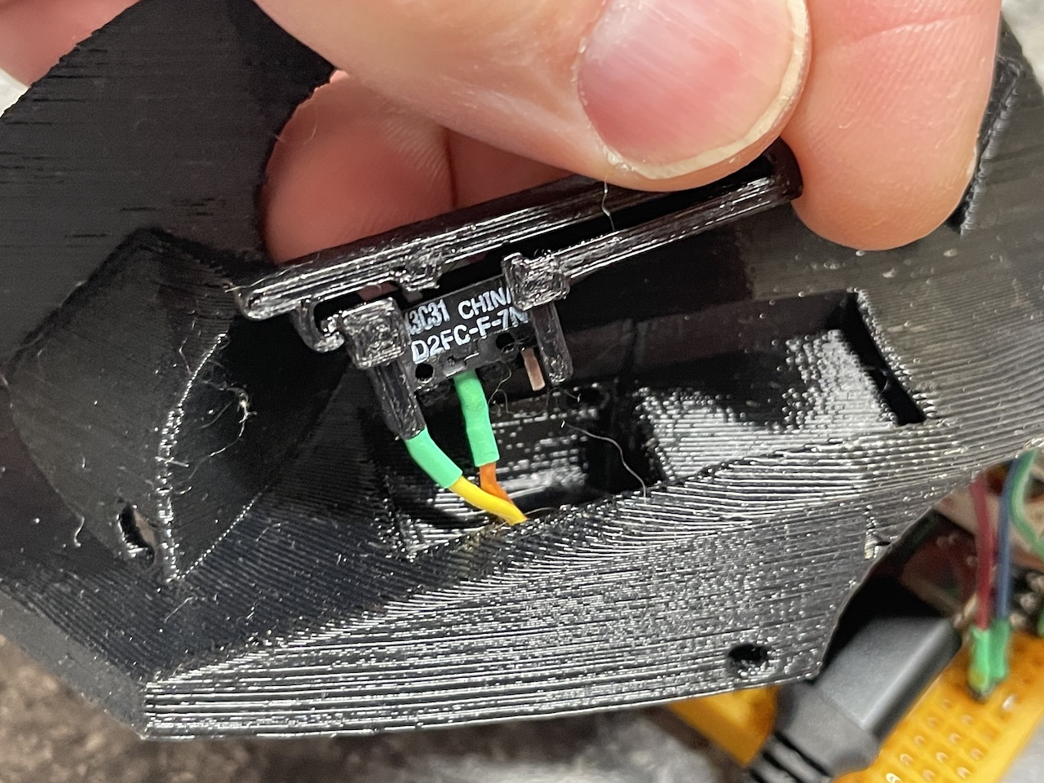
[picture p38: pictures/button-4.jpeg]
<br>
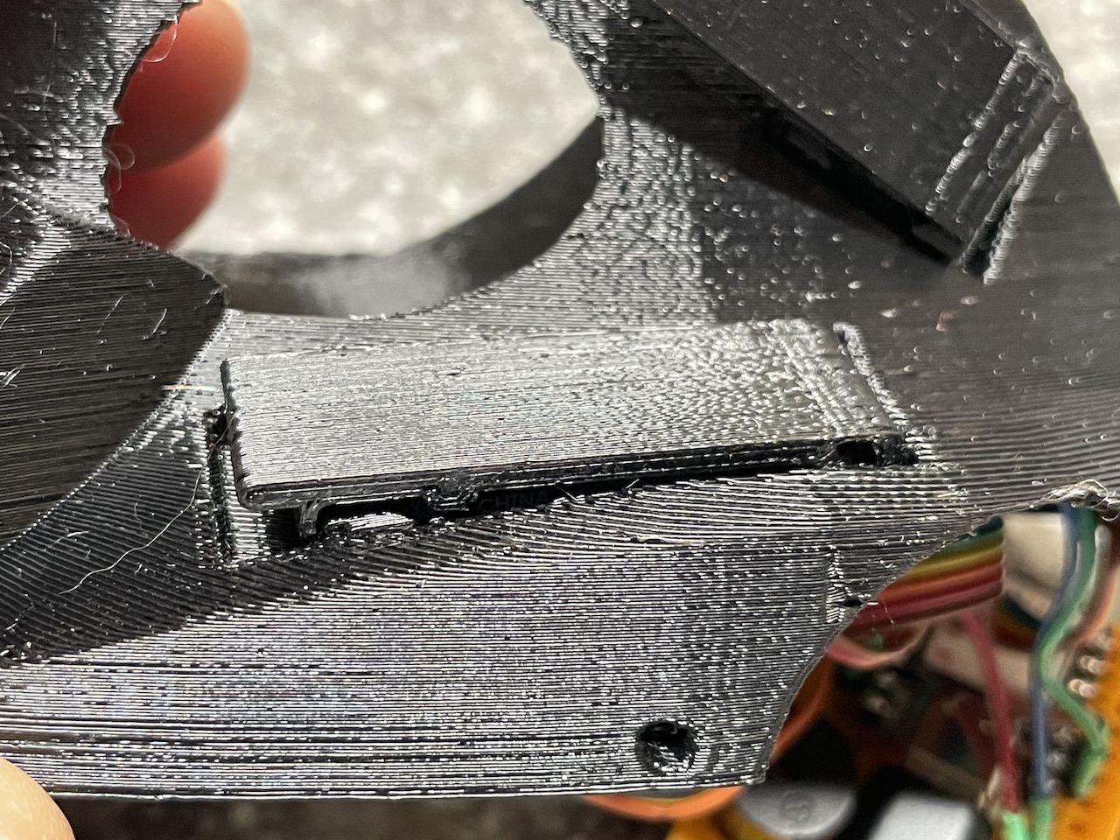
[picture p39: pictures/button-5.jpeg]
<br>

The wires run through the wiring channels underneath.<br>

Carefully bundle the extra wires above the breadboard, plug in your USB cable, and insert the breadboard into the matching cutout under the hand-rest. Route the wires around the sensor, and ensure they don't get pinched between the sides of the breadboard and the body.<br>

The bottom of the breadboard should sit flush with the bottom of the body, and all the wires should run thorugh the cutouts, so the whole thing should be able to sit flat on the table when you're done.<br>

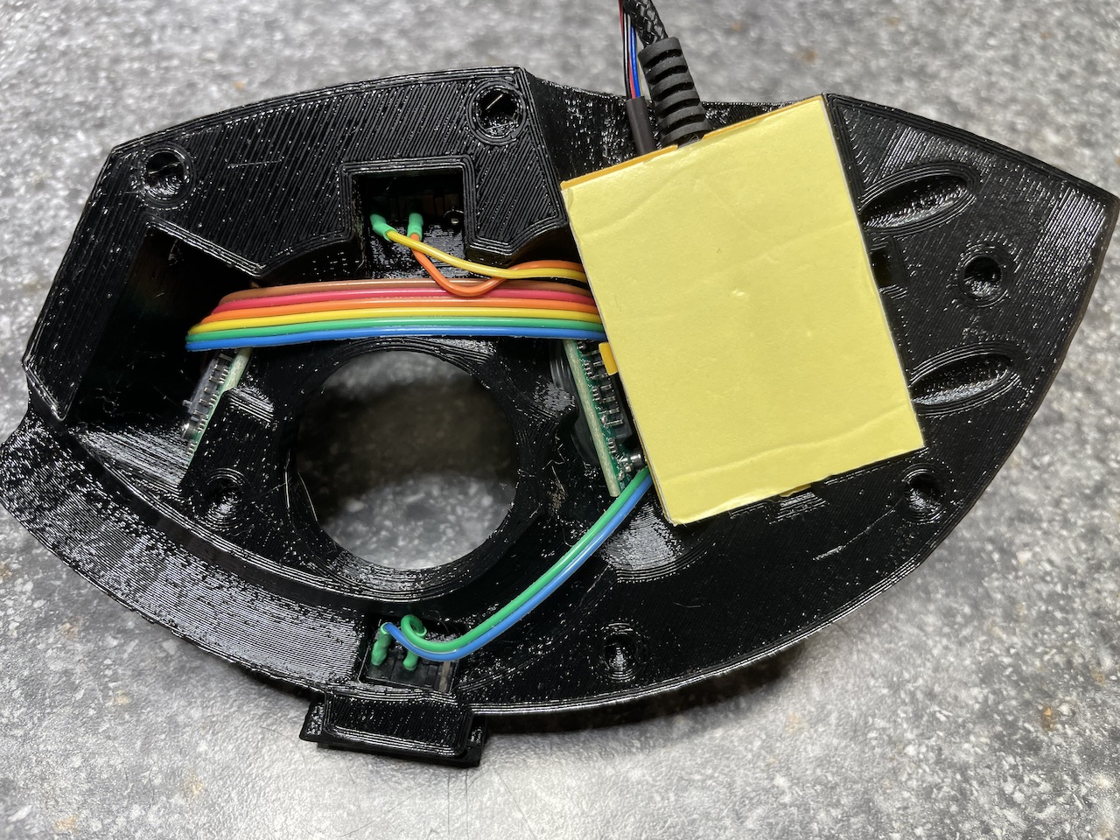
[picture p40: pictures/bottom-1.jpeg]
<br>

To finish it all off, print a copy of the `bottom_cover()` module from trackball.scad. It has little round nubs that snap into matching holes in the bottom of the body and hold it in place. It's likely to be a bit hard to snap on and off the first couple of times (dependent on the dimensional accuracy of your printer).<br>

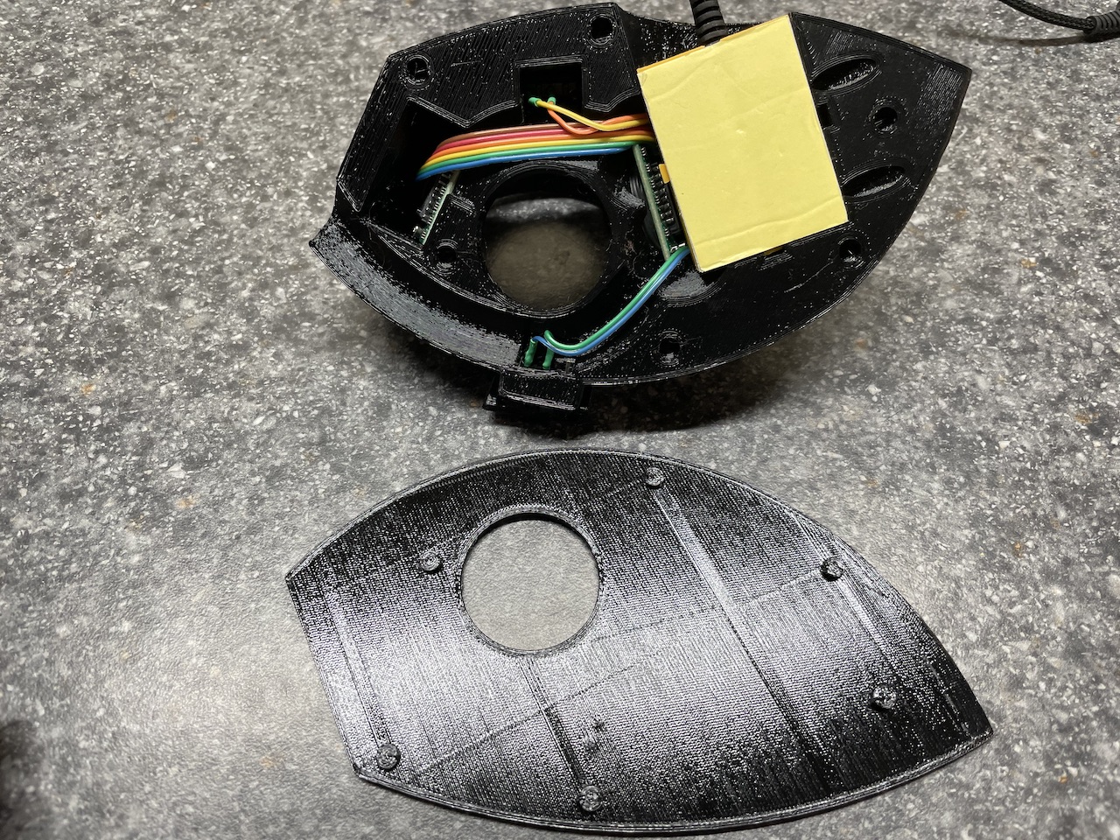
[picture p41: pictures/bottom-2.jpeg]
<br>
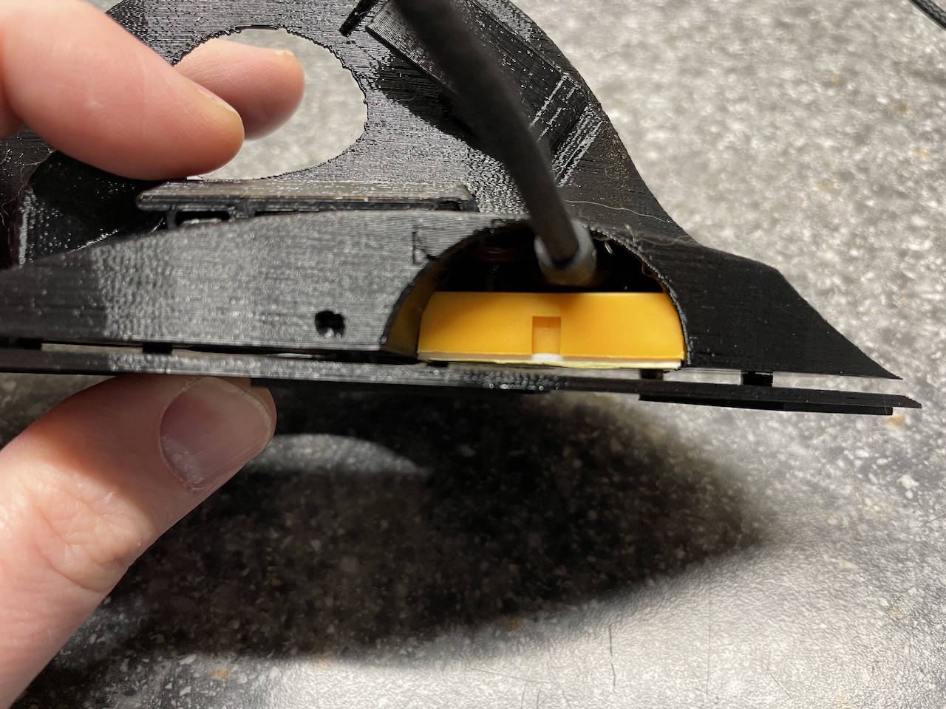
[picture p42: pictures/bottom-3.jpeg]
<br>
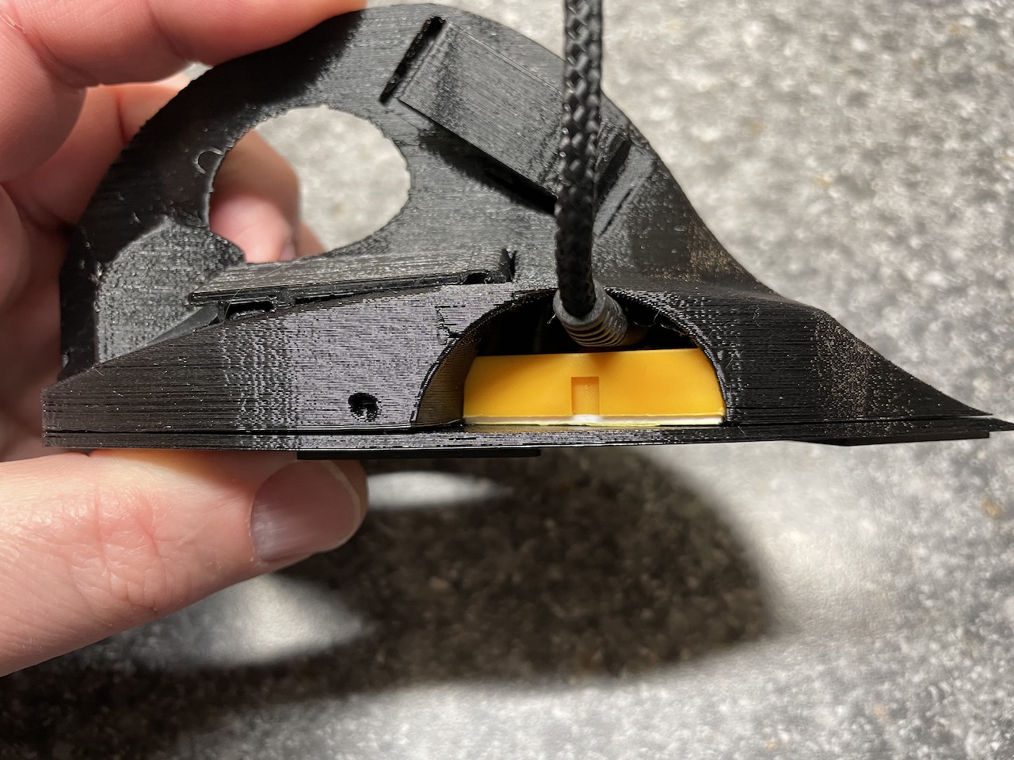
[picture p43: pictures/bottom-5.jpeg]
<br>

I recommend sticking some very thin rubber feet or adhesive rubber sheet to the bottom, to keep it from sliding around on the desk. I used the leftovers from some little sheets of adhesive rubber feet I had lying around, which are only around 1mm thick. <br>

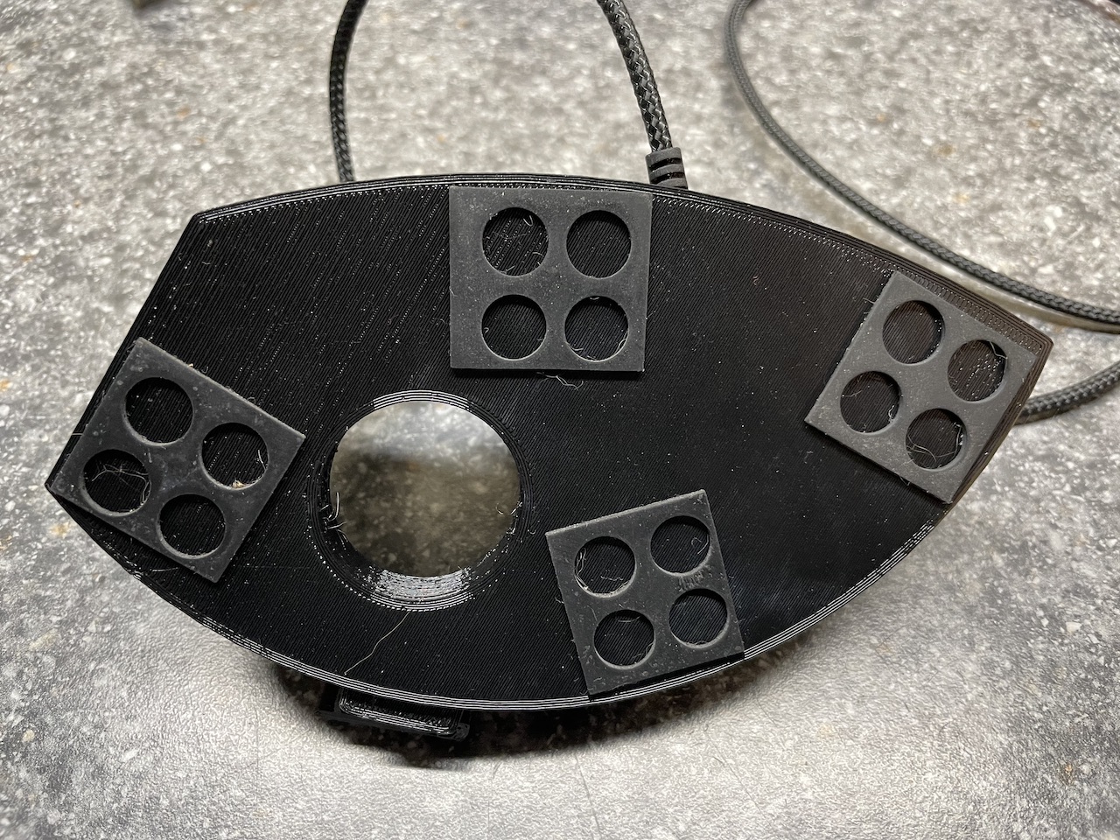
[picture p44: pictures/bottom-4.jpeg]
<br>

That's it. Enjoy! <br>

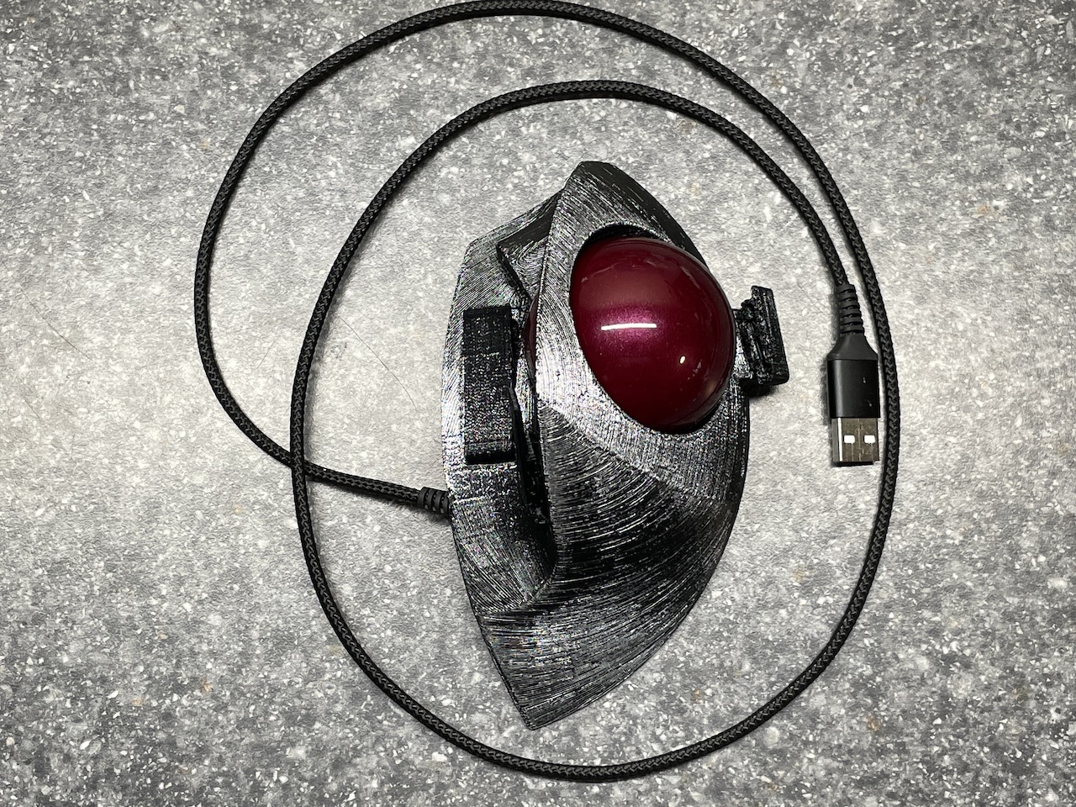
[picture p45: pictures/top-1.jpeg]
<br>
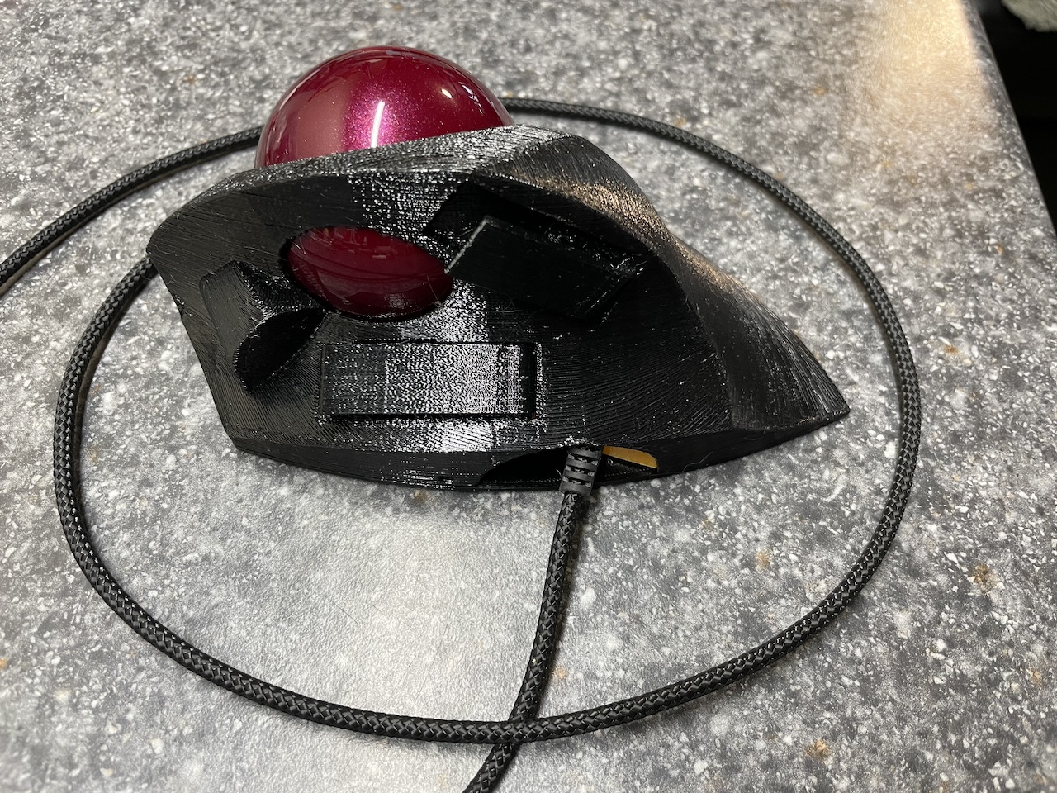
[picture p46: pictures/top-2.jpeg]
<br>
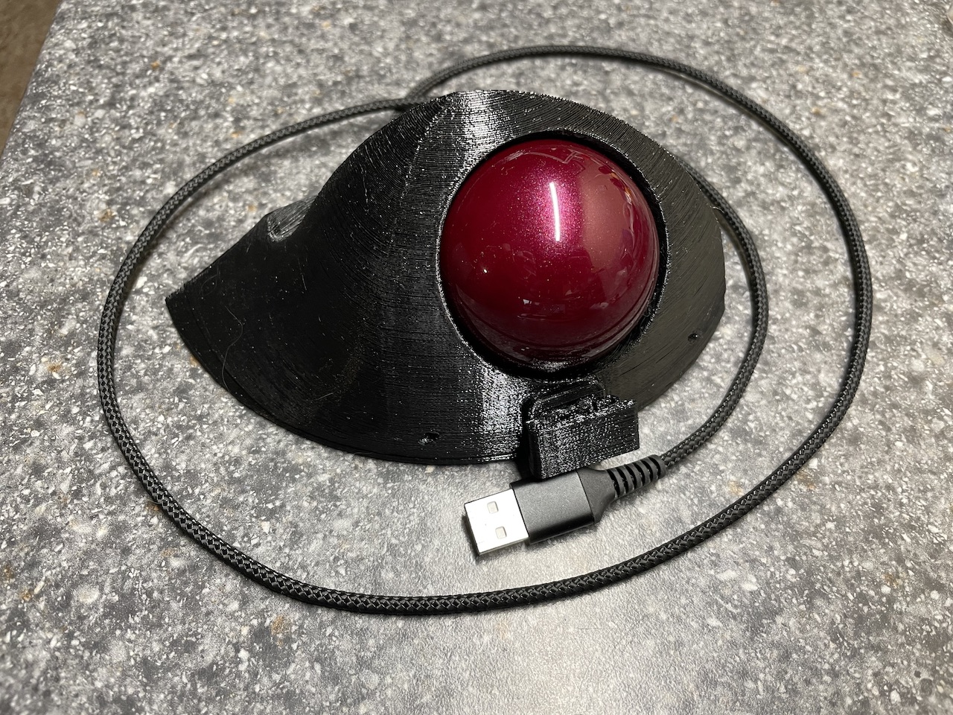
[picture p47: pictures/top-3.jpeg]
<br>

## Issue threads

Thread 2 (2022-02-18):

What version of openscad to use to render?

elliotf, 2022-02-18:
:wave: Hello, and thank you for sharing your trackball design!

I'm attempting to get up and going, but I'm trying to find a version of openscad that will correctly render.

I've tried openscad-nightly of 2022/02/10 as well as an older stable version of 2019/05, and neither render correctly, resulting in what looks like the two sensor housings and one of the right mouse button housings.

I appreciate any pointers/suggestions/tips you might have, otherwise I'll start hacking away to find the source of the problem. :)

Thank you again!

elliotf, 2022-02-18:
In case it is helpful, a screenshot of what it looks like when I render HEAD:

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

elliotf, 2022-02-19:
Okay, 2019/05 is actually rendering just fine, but the nightly is very unhappy.

elliotf, 2022-02-19:
Fixed via #3

Closed 2022-02-19.

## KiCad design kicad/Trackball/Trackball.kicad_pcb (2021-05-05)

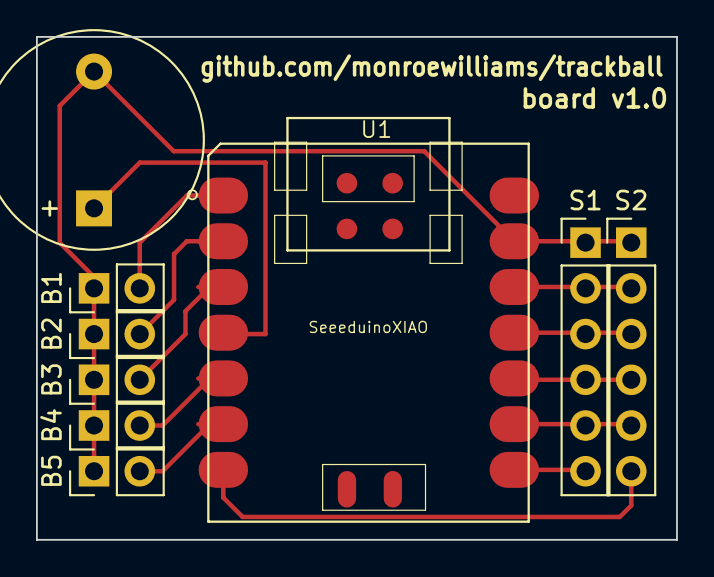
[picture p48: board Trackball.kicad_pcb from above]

Board: 2 copper layers, 35.6 x 27.9 mm, 9 parts (0 on the bottom side), 13 nets.

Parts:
B1, B2, B3, B4, B5: Conn_01x02; PinHeader_1x02_P2.54mm_Vertical
LS1: Piezo; Buzzer_12x9.5RM7.6
S1, S2: Conn_01x06; PinHeader_1x06_P2.54mm_Vertical
U1: SeeeduinoXIAO; Seeeduino XIAO-MOUDLE14P-2.54-21X17.8MM

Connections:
GND: B1.1, B2.1, B3.1, B4.1, B5.1, LS1.2, S1.1, S2.1, U1.13
unnamed: B1.2, U1.1
unnamed: B2.2, U1.2
unnamed: B3.2, U1.3
unnamed: B4.2, U1.5
unnamed: B5.2, U1.6
unnamed: LS1.1, U1.4
unnamed: S1.2, S2.2, U1.12
unnamed: S1.3, S2.3, U1.11
unnamed: S1.4, S2.4, U1.10
unnamed: S1.5, S2.5, U1.9
unnamed: S1.6, U1.8
unnamed: S2.6, U1.7

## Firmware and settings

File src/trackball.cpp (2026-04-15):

#include <SPI.h>
#include <math.h>

#include "Adafruit_TinyUSB.h"
#include <Adafruit_SleepyDog.h>
#include "trackball.h"
#include "Vector.h"
#include "adns.h"

#if defined(PIN_NEOPIXEL)
  #include <Adafruit_NeoPixel.h>
  Adafruit_NeoPixel pixel(1, PIN_NEOPIXEL);
#endif

////////////////////////////////////////
// Various config options

// This is the cpi we will report to the host. It's independent of the sensor's physical CPI.
const int reported_cpi = 800;

// This is the frequency at which we poll sensors/buttons and send HID reports.
const int report_Hz = 120;

// Use a custom HID descriptor instead of TUD_HID_REPORT_DESC_MOUSE()
#define USE_CUSTOM_HID_DESCRIPTOR 0

// Use HID_USAGE_DESKTOP_RESOLUTION_MULTIPLIER to transmit higher-fidelity scroll reports.
// Only used if USE_CUSTOM_HID_DESCRIPTOR is also set to 1.
#define USE_SCROLL_RESOLUTION_MULTIPLIER 0

// Use 16 bit fields for the X/Y deltas in the report
// Only used if USE_CUSTOM_HID_DESCRIPTOR is also set to 1.
#define USE_16_BIT_DELTAS 1

// Enable serial port debugging output
// #define SERIAL_DEBUG

// These give the option to connect a display and toggle between regular operation and displaying the images from the sensors.
// 0 - no display
// 1 - SSD1327 display on the i2c bus  ( https://www.adafruit.com/product/4741 )
// 2 - 128x128 SSD1351 on the SPI bus  ( https://www.amazon.com/gp/product/B07DB5YFGW )
// #define SENSOR_DISPLAY 1

// Use this to start out in sensor display mode. 
// Useful if you're just testing a sensor and don't have any buttons hooked up yet.
// Only used if SENSOR_DISPLAY is non-zero
// #define SENSOR_DISPLAY_ON_STARTUP

// Turn this on to make the LED light up when buttons are pressed, and fade when they're released.
// #define BUTTON_LIGHTS

// Turn this on to adjust the sensor transform for a left-handed version.
// #define LEFT_HANDED

// Turn this on to override the default device name used in the device descriptor
// #define DEVICE_NAME FooBall

///////////////////////////////////////

#if SENSOR_DISPLAY == 1
  #define SENSOR_DISPLAY_GRAY4 1
  #define SENSOR_DISPLAY_I2C 1
  #include <Adafruit_SSD1327.h>
#elif SENSOR_DISPLAY == 2
  #define SENSOR_DISPLAY_COLOR565 1
  #define SENSOR_DISPLAY_SPI 1
  #include <Adafruit_SSD1351.h>
#endif


/*
  Common pin assignments:
  standard SPI (MOSI, MISO, SCLK)
  VCC - sensor VI
  GND - sensor DG & AG
*/

#ifdef ARDUINO_AVR_PROMICRO8
  #include <avr/pgmspace.h>
  // Pin assignments on Sparkfun Pro Micro:
  // piezo speaker +
  #define PIN_PIEZO 3
  // Mouse button inputs
  #define PIN_BUTTON_LEFT 4 
  #define PIN_BUTTON_MIDDLE 5 
  #define PIN_BUTTON_RIGHT 6 
  // Select pins for sensors
  #define PIN_SENSOR_1_SELECT 18  
  #define PIN_SENSOR_2_SELECT 19  
#endif  

#if defined(PINS_QTPY)
  // Pin assignments on Seeeduino XIAO/Adafruit QT Py:
  // piezo speaker +
  #define PIN_PIEZO A3
  // Mouse button inputs
  #define PIN_BUTTON_LEFT A0 
  #define PIN_BUTTON_RIGHT A1 
  #define PIN_BUTTON_MIDDLE A2 

  // SPI Select pins for sensors
  // Sadly, these have different/incompatible definitions on the QT Py RP2040.
  #if defined(PINS_QTPY_RP2040)
    #define PIN_SENSOR_1_SELECT PIN_SERIAL2_RX  
    #define PIN_SENSOR_2_SELECT PIN_SERIAL2_TX  
  #else
    #define PIN_SENSOR_1_SELECT A7  
    #define PIN_SENSOR_2_SELECT A6  
  #endif

  // Testing: use software SPI
  // #define SENSOR_1_SOFTWARE_SPI     PIN_SPI_SCK, PIN_SPI_MISO, PIN_SPI_MOSI
  // #define SENSOR_2_SOFTWARE_SPI     PIN_SPI_SCK, PIN_SPI_MISO, PIN_SPI_MOSI

  // Defs for the Wire interface for the display
  // It will be plugged into the Stemma Qt plug
  #if defined(PINS_QTPY_RP2040)
    // On this board, the plug is Wire1
    #define DISPLAY_PIN_SDA PIN_WIRE1_SDA
    #define DISPLAY_PIN_SCL PIN_WIRE1_SCL
    #define DISPLAY_WIRE_DEVICE Wire1
  #else
    // On the original QT PY, the plug is just Wire
    #define DISPLAY_PIN_SDA PIN_WIRE_SDA
    #define DISPLAY_PIN_SCL PIN_WIRE_SCL
    #define DISPLAY_WIRE_DEVICE Wire
  #endif

#elif defined(PINS_CUSTOM_BOARD)
  // PIN_PIEZO is already defined in the variant's pins_arduino.h

   // Mouse button inputs
  #define PIN_BUTTON_LEFT PIN_B16 
  #define PIN_BUTTON_RIGHT PIN_B17 
  #define PIN_BUTTON_MIDDLE PIN_B18 

  // SPI Select pins for sensors

  // sensor 1
  // hardware SPI on SPI0.8 connector
  #define PIN_SENSOR_1_SELECT PIN_SPI0_SS08
  #define SENSOR_1_SPI_DEVICE SPI

  // sensor 2
#if 1
  // hardware SPI on SPI0.9 connector
  #define PIN_SENSOR_2_SELECT PIN_SPI0_SS09
  #define SENSOR_2_SPI_DEVICE SPI
#elif 0
  // hardware SPI on SPI1.13 connector
  #define PIN_SENSOR_2_SELECT PIN_SPI1_SS
  #define SENSOR_2_SPI_DEVICE SPI1
#else
  // software SPI on breakout connector
  #define PIN_SENSOR_2_SELECT PIN_BREAKOUT1
    // define these as sck, miso, mosi
  #define SENSOR_2_SOFTWARE_SPI   PIN_BREAKOUT4, PIN_BREAKOUT3, PIN_BREAKOUT2
#endif

  // Defs for the Wire interface for the display
  // It will be plugged into the Stemma Qt plug, a.k.a. Wire
  #define DISPLAY_PIN_SDA PIN_WIRE0_SDA
  #define DISPLAY_PIN_SCL PIN_WIRE0_SCL
  #define DISPLAY_WIRE_DEVICE Wire

#endif

// Button state polling/tracking
const char buttonNames[] = { MOUSE_BUTTON_LEFT, MOUSE_BUTTON_RIGHT, MOUSE_BUTTON_MIDDLE };
const int buttonPins[] = { PIN_BUTTON_LEFT, PIN_BUTTON_RIGHT,  PIN_BUTTON_MIDDLE };
const int buttonCount = sizeof(buttonPins) / sizeof(buttonPins[0]);
char buttons;

// HID report descriptor using TinyUSB's template
// Single Report (no ID) descriptor
uint8_t const desc_hid_report[] =
{
#if !USE_CUSTOM_HID_DESCRIPTOR
  TUD_HID_REPORT_DESC_MOUSE()
#else
  HID_USAGE_PAGE ( HID_USAGE_PAGE_DESKTOP      )                   ,
  HID_USAGE      ( HID_USAGE_DESKTOP_MOUSE     )                   ,
  HID_COLLECTION ( HID_COLLECTION_APPLICATION  )                   ,
    /* Report ID if any */
    // __VA_ARGS__ 
    HID_USAGE      ( HID_USAGE_DESKTOP_POINTER )                   ,
    HID_COLLECTION ( HID_COLLECTION_PHYSICAL   )                   ,
      HID_USAGE_PAGE  ( HID_USAGE_PAGE_BUTTON  )                   ,
        HID_USAGE_MIN   ( 1                                      ) ,
        HID_USAGE_MAX   ( 5                                      ) ,
        HID_LOGICAL_MIN ( 0                                      ) ,
        HID_LOGICAL_MAX ( 1                                      ) ,
        /* Left, Right, Middle, Backward, Forward buttons */ 
        HID_REPORT_COUNT( 5                                      ) ,
        HID_REPORT_SIZE ( 1                                      ) ,
        HID_INPUT       ( HID_DATA | HID_VARIABLE | HID_ABSOLUTE ) ,
        /* 3 bit padding */ 
        HID_REPORT_COUNT( 1                                      ) ,
        HID_REPORT_SIZE ( 3                                      ) ,
        HID_INPUT       ( HID_CONSTANT                           ) ,
      HID_USAGE_PAGE  ( HID_USAGE_PAGE_DESKTOP )                   ,
        /* X, Y position [-127, 127] */ 
        HID_USAGE       ( HID_USAGE_DESKTOP_X                    ) ,
        HID_USAGE       ( HID_USAGE_DESKTOP_Y                    ) ,
#if USE_16_BIT_DELTAS
        HID_LOGICAL_MIN_N ( SHRT_MIN, 2                          ) ,
        HID_LOGICAL_MAX_N ( SHRT_MAX, 2                          ) ,
        HID_REPORT_COUNT( 2                                      ) ,
        HID_REPORT_SIZE ( 16                                     ) ,
#else
        HID_LOGICAL_MIN ( 0x81                                   ) ,
        HID_LOGICAL_MAX ( 0x7f                                   ) ,
        HID_REPORT_COUNT( 2                                      ) ,
        HID_REPORT_SIZE ( 8                                      ) ,
#endif
        HID_INPUT       ( HID_DATA | HID_VARIABLE | HID_RELATIVE ) ,
    HID_COLLECTION_END                                             , 
    HID_COLLECTION ( HID_COLLECTION_LOGICAL   )                    ,
#if USE_SCROLL_RESOLUTION_MULTIPLIER
      HID_USAGE_PAGE  ( HID_USAGE_PAGE_DESKTOP )                   ,
        HID_USAGE       ( HID_USAGE_DESKTOP_RESOLUTION_MULTIPLIER) ,
        HID_LOGICAL_MIN ( 0                                      ) ,
        HID_LOGICAL_MAX ( 255                                    ) ,
        HID_PHYSICAL_MIN( 1                                      ) ,
        HID_PHYSICAL_MAX_N( 256, 2                               ) ,
        HID_REPORT_COUNT( 1                                      ) ,
        HID_REPORT_SIZE ( 8                                      ) ,
        HID_INPUT       ( HID_DATA | HID_VARIABLE | HID_ABSOLUTE ) ,
#endif
      HID_USAGE_PAGE  ( HID_USAGE_PAGE_DESKTOP )                   ,
        /* Veritcal wheel scroll [-127, 127] */ 
        HID_USAGE       ( HID_USAGE_DESKTOP_WHEEL                )  ,
        HID_LOGICAL_MIN ( 0x81                                   )  ,
        HID_LOGICAL_MAX ( 0x7f                                   )  ,
        HID_REPORT_COUNT( 1                                      )  ,
        HID_REPORT_SIZE ( 8                                      )  ,
        HID_INPUT       ( HID_DATA | HID_VARIABLE | HID_RELATIVE )  ,
      HID_USAGE_PAGE  ( HID_USAGE_PAGE_CONSUMER ), 
       /* Horizontal wheel scroll [-127, 127] */ 
        HID_USAGE_N     ( HID_USAGE_CONSUMER_AC_PAN, 2           ), 
        HID_LOGICAL_MIN ( 0x81                                   ), 
        HID_LOGICAL_MAX ( 0x7f                                   ), 
        HID_REPORT_COUNT( 1                                      ), 
        HID_REPORT_SIZE ( 8                                      ), 
        HID_INPUT       ( HID_DATA | HID_VARIABLE | HID_RELATIVE ), 
    HID_COLLECTION_END                                            , 
  HID_COLLECTION_END 
#endif
};

// USB HID object
Adafruit_USBD_HID usb_hid;

const int report_microseconds = 1000000 / report_Hz;

// The coordinate system here is a bit wonky -- in the final HID report, +X points right and +Y points "down" (towards the user),
// and the direction of Z is arbitrary since we're translating it to scrollwheel ticks.
// We're also conflating linear motion on the X/Y plane of each sensor tangent to the ball with rotation of the ball in X/Y/Z

// sensor locations:
// S#A = azimuth = degrees clockwise from 12 o'clock (directly away from the user)
// S#E = elevation = degrees down from horizontal
#define S1A 180
#define S1E 30
#define S2A (270 + 45)
#define S2E 30

// TODO: build a transform from the azimuth/elevation constants.

// The sensor transform
// Note that the sensor orientation I've been using all along is actually "sideways", for mechanical reasons
// i.e. the X axis of the sensor points up/down, and the Y axis points parallel to the desk.
// This transform takes that into account.
float st[3][4] = 
{
#if !defined(LEFT_HANDED)
  // This is the "hack" transform I've been using for the new sensor location 
  // (s1 at 180, s2 at  270 + 45, both at 30 degrees elevation)
  { -1,        0,       -sqrtf(2.0),  0   },  // X is s2.x, scaled up a bit, with s1.x subtracted to compensate for s2 being off-axis
  {  1,        0,        0,           0   },  // Y is s1.x
  {  0,       -0.5,      0,          -0.5 }   // Z is the average of the two sensors' y components.
#else
  // This is the transform for the left-handed version, where the main body has been mirrored.
  {  1,        0,        sqrtf(2.0),  0   },  // X is s2.x, scaled up a bit, with s1.x subtracted to compensate for s2 being off-axis
  {  1,        0,        0,           0   },  // Y is s1.x
  {  0,       -0.5,      0,          -0.5 }   // Z is the average of the two sensors' y components.
#endif

  // This was the transform for the original sensor location (s1 at 180 and s2 at 270, at zero elevation)
  // {  0,        0,       -1,     0   },    // X is the inverse of the direct x reading of s2
  // {  1,        0,        0,     0   },    // Y is the direct x reading of s1
  // {  0,       -0.5,      0,    -0.5  }    // Z is the average of the two sensors' y components.
};

// sensor hardware abstraction
adns s1(PIN_SENSOR_1_SELECT, reported_cpi
#if defined(SENSOR_1_SPI_DEVICE)
  , SENSOR_1_SPI_DEVICE
#elif defined(SENSOR_1_SOFTWARE_SPI)
  , SENSOR_1_SOFTWARE_SPI
#endif
);

#if defined(PIN_SENSOR_2_SELECT)
  adns s2(PIN_SENSOR_2_SELECT, reported_cpi
  #if defined(SENSOR_2_SPI_DEVICE)
    , SENSOR_2_SPI_DEVICE
  #elif defined(SENSOR_2_SOFTWARE_SPI)
    , SENSOR_2_SOFTWARE_SPI
  #endif
  );
#else
  // make s2 a dummy sensor, for testing
  adns s2;
#endif

// scrolling
const int scroll_tick = 64;
float scroll_accum = 0;


#if SENSOR_DISPLAY == 1
  Adafruit_SSD1327 display(128, 128, &DISPLAY_WIRE_DEVICE, -1, 2000000UL);
  const int display_address = SSD1327_I2C_ADDRESS;
  const uint16_t text_color = SSD1327_WHITE;
  const uint16_t text_bg = SSD1327_BLACK;
#elif SENSOR_DISPLAY == 2
  #define DISPLAY_DC_PIN   4
  #define DISPLAY_CS_PIN   5
  #define DISPLAY_RST_PIN  -1
  Adafruit_SSD1351 display = Adafruit_SSD1351(128, 128, &SPI, DISPLAY_CS_PIN, DISPLAY_DC_PIN, DISPLAY_RST_PIN);
  const uint16_t text_color = 0xFFFF;
  const uint16_t text_bg = 0x0000;
#endif

#if defined(SENSOR_DISPLAY)
bool sensor_display_mode = false;
bool display_ready = false;
bool sensor_display_zoom_select = false;
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
void loop() 
{
  unsigned long loop_start_time = micros();
  // Time taken by the last loop, saved so we can display it during the next loop.
  static unsigned long loop_time = 0;
  bool sendReport = false;
  bool sendWakeup = false;
  Vector delta;
  int scroll = 0;

#if SENSOR_DISPLAY
  if(sensor_display_mode)
  {
    display_sensors();
  }
  else
#endif
  {
    // Poll sensors for mouse movement

    // v1 and v2 contain the floating point x/y motion values from each sensor, 
    // scaled from the sensor's CPI to units of reported_cpi.
    Vector v1 = s1.motion();
    Vector v2 = s2.motion();

#if 0
    // Print all values from the burst.
    // Possibly useful for tweaking sensor parameters.
    debugLogger.printf("s1: ");
    printBurst(s1);
    debugLogger.printf("s2: ");
    printBurst(s2);
#endif

#if 0
    // Useful when debugging sensor scaling
    debugLogger.print(F("report_cpi = "));
    debugLogger.print(s1.report_cpi);
    debugLogger.print(F(", current_cpi = "));
    debugLogger.print(s1.current_cpi);
    debugLogger.print(F(", cpi_scale_factor = "));
    debugLogger.print(s1.cpi_scale_factor);
    debugLogger.print(F(", x = "));
    debugLogger.print(s1.x);
    debugLogger.print(F(", y = "));
    debugLogger.print(s1.y);
    debugLogger.print(F(", v = "));
    debugLogger.print(v1);
    debugLogger.println("");
#endif

    // Given the way my design mounts the sensors (with the wire attachment at the top), the 9800 is inverted relative to the others.
    if (s1.sensor_type() == adns::PID_adns9800)
    {
      v1 = -v1;
    }
    if (s2.sensor_type() == adns::PID_adns9800)
    {
      v2 = -v2;
    }

    if (v1.x != 0 || v1.y != 0 || v2.x != 0 || v2.y != 0)
    {
      // The sensor reported movement.

      // multiply the sensor transform matrix by the vector of [v1.x, v1.y, v2.x, v2.y]
      delta = Vector(
        st[0][0] * v1.x + st[0][1] * v1.y + st[0][2] * v2.x + st[0][3] * v2.y, 
        st[1][0] * v1.x + st[1][1] * v1.y + st[1][2] * v2.x + st[1][3] * v2.y, 
        st[2][0] * v1.x + st[2][1] * v1.y + st[2][2] * v2.x + st[2][3] * v2.y
      );

      ////// This is probably only useful when actively debugging sensor readings or the transform matrix.
      ////// Otherwise it gets very spammy.
      // debugLogger.print(F("v1 = "));
      // debugLogger.print(v1);
      // debugLogger.print(F(", v2 = "));
      // debugLogger.print(v2);
      // debugLogger.print(F(", delta = "));
      // debugLogger.print(delta);
      // debugLogger.println("");

      // Figure out if we should scroll
      if ((fabs(delta.z) > (fabs(delta.x) * 2)) && (fabs(delta.z) > (fabs(delta.y) * 2)))
      {
        // Looks like we're scrolling more than not.
        scroll_accum += delta.z;
        scroll = scroll_accum / scroll_tick;
        scroll_accum -= scroll * scroll_tick;

        // When we're scrolling, disable x/y movement
        delta.x = 0;
        delta.y = 0;
        // debugLogger.print("Calculated scroll = ");
        // debugLogger.print(scroll);
        // debugLogger.print(", scroll_accum =  ");
        // debugLogger.println(scroll_accum);
      }
      else
      {
        delta.z = 0;
      }

      if (scroll != 0)
      {
          click();
      }
      if ((delta.x != 0) || (delta.y != 0) || 
#if USE_SCROLL_RESOLUTION_MULTIPLIER
        (delta.z != 0)
#else
        (scroll != 0)
#endif
      )
      {
        sendReport = true;
      }
    }
  }
  
  // Poll for button states 
  if(1)
  {
    for(int i=0; i<buttonCount; i++)
    {
      int name = buttonNames[i];
      if (digitalRead(buttonPins[i]) == LOW)
      {
#if defined(BUTTON_LIGHTS)
        // For the first three buttons, set a color whenever the button is down
        switch(i)
        {
          case 0: ledRed = 1.0; break;
          case 1: ledGreen = 1.0; break;
          case 2: ledBlue = 1.0; break;
          default: break;
        }
#endif
        if (!(buttons & name))
        {
          // debugLogger.print(F("pressing mouse button "));
          // debugLogger.println(name);
          buttons |= name;
          sendReport = true;
          sendWakeup = true;
        }
      }
      else
      {
        if (buttons & name)
        {
          // debugLogger.print(F("releasing mouse button "));
          // debugLogger.println(name);
          buttons &= ~name;
          sendReport = true;
          sendWakeup = true;
        }
      }
    }
#if SENSOR_DISPLAY
    // Only if the display was found on startup...
    if (display_ready)
    {
      // Check for the toggle condition
      static char prevButtons = 0;
      if (prevButtons == 0x07 && buttons != 0x07)
      {
        // All 3 buttons were pressed
        set_sensor_display(!sensor_display_mode);
      }
      else if (sensor_display_mode)
      {
          // If we're in sensor display mode, the main button toggles zoom focus
          if (prevButtons == 0x01 && buttons == 0x00)
          {
            sensor_display_zoom_select = !sensor_display_zoom_select;
            // Erase the sensor draw area
            const int max_sensor_draw_size = ((36 * 2) + 2);
            display.fillRect(
              0, 
              display.height() - max_sensor_draw_size,
              display.width(),
              max_sensor_draw_size,
              text_bg);
          }
      }
      prevButtons = buttons;
    }
#endif

  }
  if (sendWakeup && USBDevice.suspended())
  {
    USBDevice.remoteWakeup();
  }
  if (sendReport)
  {
    #define CLAMP(val, min, max) (val > max)?max:((val < min)?min:val)
#if !USE_CUSTOM_HID_DESCRIPTOR
      // if (scroll != 0)
      // {
      //   debugLogger.print("reporting wheel = ");
      //   debugLogger.println(scroll);
      // }
      usb_hid.mouseReport(
        0, 
        buttons, 
        CLAMP(delta.x, SCHAR_MIN, SCHAR_MAX),
        CLAMP(delta.y, SCHAR_MIN, SCHAR_MAX),
        CLAMP(scroll, SCHAR_MIN, SCHAR_MAX),
        0);
#else
#if USE_16_BIT_DELTAS
    typedef int16_t delta_t;
    const int delta_min = SHRT_MIN;
    const int delta_max = SHRT_MAX;
#else
    typedef int8_t delta_t;
    const int delta_min = SCHAR_MIN;
    const int delta_max = SCHAR_MAX;
#endif

    // With the resolution multiplier, we have deviated from the standard mouse report.
    // Roll our own here.
    typedef struct TU_ATTR_PACKED
    {
      uint8_t buttons;    /**< buttons mask for currently pressed buttons in the mouse. */
      delta_t  x;         /**< Current delta x movement of the mouse. */
      delta_t  y;         /**< Current delta y movement on the mouse. */
#if USE_SCROLL_RESOLUTION_MULTIPLIER
      uint8_t  multiplier; /**< Mouse wheel resolution multiplier */
#endif
      int8_t  wheel;      /**< Current delta wheel movement on the mouse. */
      int8_t  pan;        // using AC Pan
    } report_t;

    report_t report =
    {
      .buttons = buttons,
      .x       = delta_t(CLAMP(delta.x, delta_min, delta_max)),
      .y       = delta_t(CLAMP(delta.y, delta_min, delta_max)),
#if USE_SCROLL_RESOLUTION_MULTIPLIER
      .multiplier = uint8_t(scroll_tick - 1),
      .wheel   = int8_t(CLAMP(delta.z, SCHAR_MIN, SCHAR_MAX)),
#else
      .wheel   = int8_t(CLAMP(scroll, SCHAR_MIN, SCHAR_MAX)),
#endif
      .pan     = 0
    };

//     if (report.wheel != 0)
//     {
//       debugLogger.print("reporting wheel = ");
//       debugLogger.print(report.wheel);
// #if USE_SCROLL_RESOLUTION_MULTIPLIER
//       debugLogger.print(", multiplier = ");
//       debugLogger.print(report.multiplier);
// #endif
//       debugLogger.println("");
//     }

    (void)tud_hid_report(0, &report, sizeof(report));
#endif
  }
#if SENSOR_DISPLAY  
  if (display_ready)
  {
    ////////
    // This may be useful for debugging, but it brings us down to ~30hz with the i2c display.
#if 0
    display.fillRect(0, 0, 128, 16, 0);
    display.setCursor(0,0);
    display.println(delta);
    display.print(F("loop time "));
    display.print(loop_time / 1000);
    display.print(F("ms"));
#if defined(SENSOR_DISPLAY_GRAY4)
    display.display();
#endif
#endif
    ////////
    // Trying to diagnose an issue with kvm switching. This lets me see if the device resets on switch.
#if 0
    static unsigned long last_uptime_seconds = 0;
    unsigned long uptime_seconds = millis() / 1000;
    if (uptime_seconds != last_uptime_seconds)
    {
      last_uptime_seconds = uptime_seconds;
      // Default font is 6x8
      display.setCursor(0,0);
      display.printf("%02d:%02d:%02d", uptime_seconds / 3600, (uptime_seconds / 60) % 60, (uptime_seconds) % 60);
#if defined(SENSOR_DISPLAY_GRAY4)
      display.display();
#endif
    }
#endif

  }
#endif
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

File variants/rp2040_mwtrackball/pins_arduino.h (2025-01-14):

#pragma once

// LED (N/A)
#define PIN_LED        (31u)

// NeoPixel
#define PIN_NEOPIXEL   (11u)
// NeoPixel is always powered on this board.
// #define NEOPIXEL_POWER (31u)

// Serial (N/A)
#define PIN_SERIAL1_TX (31u)
#define PIN_SERIAL1_RX (31u)
#define PIN_SERIAL2_TX (31u)
#define PIN_SERIAL2_RX (31u)

// SPI
#define PIN_SPI0_MISO  (4u)
#define PIN_SPI0_MOSI  (7u)
#define PIN_SPI0_SCK   (2u)
// No SS pin specified to the library, code will set it manually.
// Pins routed to the connectors are GPIO8 and GPIO9 
#define PIN_SPI0_SS    (31u)
#define PIN_SPI0_SS08  (8u)
#define PIN_SPI0_SS09  (9u)

#define PIN_SPI1_MISO  (12u)
#define PIN_SPI1_MOSI  (15u)
#define PIN_SPI1_SCK   (10u)
// Pin routed to the connector is GPIO13, as labelled on the board.
#define PIN_SPI1_SS    (13u)

// Wire0 (connected to STEMMA QT connector)
#define PIN_WIRE0_SDA (0u)
#define PIN_WIRE0_SCL (1u)
// Wire1 (N/A)
#define PIN_WIRE1_SDA (31u)
#define PIN_WIRE1_SCL (31u)

// on-board piezo speaker
#define PIN_PIEZO (24u)

// Button connectors
#define PIN_B16       (16u)
#define PIN_B17       (17u)
#define PIN_B18       (18u)
#define PIN_B19       (19u)
#define PIN_B20       (20u)
#define PIN_B21       (21u)

// pins routed to the breakout connector
#define PIN_BREAKOUT1 (26u)
#define PIN_BREAKOUT2 (27u)
#define PIN_BREAKOUT3 (28u)
#define PIN_BREAKOUT4 (29u)

// parameters for the common header and library code
#define SERIAL_HOWMANY (0u)
#define SPI_HOWMANY    (2u)
#define WIRE_HOWMANY   (1u)

// Include variants/generic/common.h from framework-arduinopico 
// This should be the correct relative path off the existing framework include path 
//     "[...]/framework-arduinopico/include"
#include "../variants/generic/common.h"

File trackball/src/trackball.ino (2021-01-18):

#include <SPI.h>
#include <avr/pgmspace.h>

#if ARDUINO >= 10606
  // If we have support for pluggable HID/USB modules, make this device look like just a mouse.
  #include <HID.h>
  #include <Mouse.h>
#endif

#include "trackball.h"

#include "adns.h"

/*
  Pin assignments on Sparkfun Pro Micro:
  
  4 - left button
  5 - middle button
  6 - right button
  3 - piezo speaker +
  
  16 - SPI MOSI (MO)
  14 - SPI MISO (MI)
  15 - SPI SCLK (SC)
  18 - sensor 1 chip select (SS)
  19 - sensor 2 chip select (SS)
  
  VCC - sensor VI
  GND - sensor DG & AG
  
*/

byte initComplete = 0;

adns sensor_1;
adns sensor_2;

// Button state polling/tracking
const int buttonCount = 3;
const char buttonNames[3] = {MOUSE_LEFT, MOUSE_MIDDLE, MOUSE_RIGHT};
const int buttonPins[3] = {4, 5, 6};

const int piezo_pin = 3;

const int scroll_tick = 128;
int scroll_accum = 0;

void setup() 
{
  Mouse.begin();
  
#if SERIAL_DEBUG
  Serial.begin(9600);
  // Add a short delay so I can get the console open before things start happening.
  delay(3000);
#endif
    
  SPI.begin();
  
  sensor_1.init(18);
  sensor_2.init(19);
  
  sensor_1.set_cpi(2400);
  sensor_1.set_snap_angle(1);
  sensor_2.set_cpi(2400);
  sensor_2.set_snap_angle(1);

  for(int i=0; i<buttonCount; i++)
  {
      pinMode(buttonPins[i], INPUT_PULLUP);
  }
  
  // Piezo output
  pinMode(piezo_pin, OUTPUT);
  
  initComplete = 1;
}

void click()
{
  digitalWrite(piezo_pin, HIGH);
  delay(1);
  digitalWrite(piezo_pin, LOW);
}


void loop() 
{
  // Poll sensors for mouse movement
  {
      sensor_1.read_motion();
      sensor_2.read_motion();
      
      if (sensor_1.x != 0 || sensor_1.y != 0 || sensor_2.x != 0 || sensor_2.y != 0)
      {
          DebugLog(F("1x = "));
          DebugLog(sensor_1.x);
          DebugLog(F(", 1y = "));
          DebugLog(sensor_1.y);
          DebugLog(F(", 2x = "));
          DebugLog(sensor_2.x);
          DebugLog(F(", 2y = "));
          DebugLogln(sensor_2.y);
      }

      int x = 0, y = 0, scroll = 0;

      x = -sensor_2.x;
      y = sensor_1.x;
      
      // Figure out if we should scroll
      if(1)
      {
        if ((abs(sensor_1.y) > (abs(sensor_1.x) * 2)) && (abs(sensor_2.y) > (abs(sensor_2.x) * 2)))
        {
          // Looks like we're scrolling more than not.  Take the average of the two sensors' y deltas as the scroll amount.
          scroll_accum += -((sensor_1.y + sensor_2.y) / 2);
          scroll = scroll_accum / scroll_tick;
          scroll_accum %= scroll_tick;
          // When we're scrolling, disable x/y movement
          x = 0;
          y = 0;
        }
      }
      
      if ((x != 0) || (y != 0) || (scroll != 0))
      {
        if (scroll != 0)
        {
          click();
        }
        Mouse.move(x, y, scroll);        
      }
  }
  
  // Poll for button states 
  for(int i=0; i<buttonCount; i++)
  {
    int name = buttonNames[i];
    if (digitalRead(buttonPins[i]) == LOW)
    {
      if (!Mouse.isPressed(name))
      {
        DebugLog(F("pressing mouse button "));
        DebugLogln(name);
        Mouse.press(name);
      }
    }
    else
    {
      if (Mouse.isPressed(name))
      {
        DebugLog(F("releasing mouse button "));
        DebugLogln(name);
        Mouse.release(name);
      }
    }
  }
}

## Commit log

2015-01-24 Initial checkin. Code is working with a single sensor and 3 buttons.
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2015-01-25 first attempt at using the burst read for motion reports. Not working yet, and I'm not sure why.
    [adns.cpp]
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2015-01-26 Added second sensor, fixed axes, and set up scrolling on twist
    [trackball.ino]
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2015-01-27 enable snap angle for both sensors
    [adns.cpp, trackball.ino]
2015-02-02 Make the duration of the click 1 millisecond, which makes it more audible.
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2015-08-15 Clean up serial debug. Made it switchable with a macro in trackball.h, such that it compiles down to nothing when switched off. Moved most strings used for debug logging into flash with the F() macro.
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2021-01-09 Fix a couple of warnings.
    [adns.cpp]
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2021-01-31 Fix a sign-extension bug in adns.
    [adns.cpp]
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2021-02-07 Fix a dumb bug in the button polling code.
    [trackball.cpp]
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2021-02-09 Add OpenSCAD files for printed parts.
    [microswitch-cherry-mx.scad, trackball.scad]
2021-02-09 First attempt at full model.
    [trackball.scad]
2021-02-09 remove render() calls from trackball.scad. They can be selectively added to the test file as needed.
    [trackball.scad]
2021-02-09 Add clearance to body_right_cut() so the ball can get in and out (oops...)
    [trackball.scad]
2021-02-09 Added front/rear overhang parameters to button_params.
    [trackball.scad]
2021-02-10 Next iteration, as printed.
    [test-base.scad, test.scad, trackball.scad]
2021-02-11 refined shape and button placements added cutout under handrest for the breadboard added breadboard cutout test file
    [breadboard.scad, trackball.scad]
2021-02-12 Fix typo that crept into the microswitch scad somehow.
    [microswitch-cherry-mx.scad]
2021-02-12 Another round of changes on the trackball scad.
    [test.scad, trackball.scad]
2021-02-13 Separate the switch to enable/disable scroll resolution from a separate switch to use a custom HID descriptor. Added some experimental code that tries to fuse the sensor data more accurately using tr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
    [trackball.cpp]
2021-02-13 Add third (middle) button.
    [trackball.scad]
2021-02-16 Enlarge the ball removal clearance cut slightly.
    [trackball.scad]
2021-02-16 add prender() module
    [trackball.scad]
2021-02-16 Minor test change
    [test.scad]
2021-02-16 Fix unintentional cut on front left. Factor out body_right_cut_translation() for future experiments.
    [trackball.scad]
2021-02-16 Another shape revision.
    [trackball.scad]
2021-02-17 Bigger breadboard cutout and bigger wire junction cutouts near breadboard.
    [trackball.scad]
2021-02-18 Invert both sensors for improved wire routing.
    [trackball.cpp]
2021-02-18 Run sensors at higher cpi and scale down. This will help with more accurate angle calculations later.
2021-02-18 Made rcube treat negative height the same as ccube.
    [trackball.scad]
2021-02-18 Added optional extra_height parameter to shadow_hull() (causes the hull to extend that much further below the bottom plane )
    [trackball.scad]
2021-02-18 Added bottom_cover() with attachment studs and matching stud holes in the full body.
    [trackball.scad]
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2021-02-25 Many changes to trackball.scad: - added option for pmw3360 sensor shape - changed sensor mount screw holes to accept 2mm machine screws - tweaked several things to be based on the ball diameter, to w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
    [trackball.scad]
2021-02-26 Fix a problem with the ball-removal clearance cut interfering with the bearing fit.
    [trackball.scad]
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2021-02-26 Fix burst motion read.
    [adns.cpp]
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2021-02-26 Sensor image blit loop is no longer a source of shame.
    [trackball.cpp]
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2021-03-01 Added option to not include button supports when printing the bottom cover. Defaults to omitting them.
    [trackball.scad]
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2021-03-03 Added assembly guide.
    [trackball.scad]
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2021-03-03 Reorganized trackball.scad slightly to put the most useful bits at the top.
    [trackball.scad]
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2021-03-03 Fix a minor misprint in the assembly guide
2021-03-04 Additional info around the ball size option. Brought the sensor skew angle up to the config section and defaulted it to 0, as it doesn't seem necessary with the pmw3360. Made the bottom hole diameter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
    [trackball.scad]
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2021-03-10 Add .stl files for the version of the trackball shown in the assembly guide. Specs: 55mm ball diameter pmw3360 sensors 10 degree sensor skew angle
    [bottom_cover_2mm-55mm-pmw3360.stl, microswitch-cherry-mx-15-0.stl, microswitch-cherry-mx-5-20.stl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]
2021-03-11 Renamed body_height and body_diameter to clarify that they're only used by body_minimal().
    [trackball.scad]
2021-03-11 Made button_cutout() more closely fit the profile of the front overhang.
    [trackball.scad]
2021-03-11 Added a param to button_params to allow disabling the button supports per-button. Refined third (alternate thumb) button placement. Added stl files for the refined button version of the main body and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
    [microswitch-cherry-mx-20-0.stl, trackball-55mm-pmw3360-skew0-button3mk2.stl, trackball.scad]
2021-03-11 Added a thicker (3mm vs. 2mm) version of the bottom cover stl. Renamed the existing bottom cover stl to reflect the fact that it doesn't depend on the sensor type.
    [bottom_cover_2mm-55mm.stl, bottom_cover_3mm-55mm.stl]
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2021-04-28 Add a bit more clearance around the aft sensor.
    [trackball.scad]
2021-04-28 Adjust some of the $f* parameters to increase faceting on the outer shell, to make the printed part look smoother.
    [trackball.scad]
2021-05-02 Updated stls for the 55mm model and base plate to incorporate updates.
    [bottom_cover_3mm-55mm.stl, trackball-55mm-pmw3360-skew0-button3mk2.stl]
2021-05-05 Reworked the bottom plate mounting holes to make the fit more tolerant of slight first-layer squish. Added the ability to secure the bottom plate with screws. Moved one of the holes slightly to give 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
    [bottom_cover_3mm-55mm.stl, bottom_cover_3mm-57mm.stl, trackball-55mm-pmw3360-skew0-button3mk2.stl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]
2021-05-05 Leaving the piezo pin in OUTPUT mode all the time was causing a faint, annoying noise from the piezo speaker. Don't do that.
    [trackball.cpp]
2021-05-05 Remove some obsolete STLs.
    [bottom_cover_2mm-55mm.stl, microswitch-cherry-mx-15-0.stl, trackball-55mm-pmw3360-skew10.stl]
2021-05-05 Update some comments in the configuration section of trackball.scad. Added experimental index and middle finger button options to button_params, and cleaned out some of the old commented out ones.
    [trackball.scad]
2021-05-05 Add Kicad source for the circuit board design.
    [Trackball.kicad_pcb, Trackball.sch]
2022-02-14 Refactor some of the OpenSCAD code slightly, and add .scad files showing how each of the .stl files was generated.
    [bottom_cover_3mm-55mm.scad, bottom_cover_3mm-57mm.scad, microswitch-cherry-mx-20-0.scad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]
2022-02-19 Trackball renders under openscad nightly
    Closes #2
    I don't see a difference in the model before and after, but I am still
    getting used to how this design looks.
    The reason why I wanted this:
    ```
    $ time openscad hardware/trackball.scad -o trackball.stl # OpenSCAD version 2019.05
    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
    [trackball.scad]
2022-03-21 Back out unwanted change in PR#3
    [trackball.scad]
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2022-10-03 The code which set up the sensor's CPI register(s) was completely wrong, and needed to do different things for each sensor model. At the moment I've only tested the codepath for the pmw3360, as that'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
    [adns.cpp, trackball.cpp]
2024-12-18 Updated some platformIO library references for the current state of platformIO. Added a case to platformio.ini for the QT Py RP2040. Builds but doesn't seem to work correctly yet, needs investigation.
    [trackball.cpp]
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2025-01-06 Convert to using debuglogger.printf() for most things. More flexibility with the #defines for setting up sensor attachment. Changed SERIAL_DEBUG and SENSOR_DISPLAY defines to be more easily configura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
    [adns.cpp, pins_arduino.h, trackball.cpp]
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2025-01-14 Additional clearance for the new custom pmw3360 board.
    [trackball.scad]
2025-01-14 Make breadboard tabs and the left-side breadboard access cutout optional.
    [trackball.scad]
2025-01-14 Make clearance for the custom sensor boards optional
    [trackball.scad]
2025-01-19 Add info about custom boards. Add hollow version of the trackball model.
    [trackball-55mm-pmw3360-custom-board.scad, trackball-55mm-pmw3360-custom-board.stl, trackball-55mm-pmw3360-hollow.scad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]
2025-01-22 Fix a couple of faults in the new hollow shell model.
    [trackball-55mm-pmw3360-hollow.stl, trackball-hollow.scad]
2025-01-22 Add a small clearance cutout for the main board.
    [trackball-55mm-pmw3360-hollow.stl, trackball-hollow.scad]
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2025-02-15 Updates to the hollow trackball model: Now supports using a small USB-C breakout board (roughly 12x15mm, available from Amazon or AliExpress) instead of a fixed cable.
    Updates to the main trackball model:
    bottom screws are now optional.
    Minor cleanup of $fn directives in both files.
    Cleaned up some of the old STLs and moved their corresponding .scad files to a "deprecated" directory to avoid confusion.
    [bottom_cover_3mm-52.5mm.scad, bottom_cover_3mm-52.5mm.stl, trackball-52.5mm-pmw3360-hollow.scad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]
2025-02-15 Major revision to the microswitch carrier, I'm calling it version 2. The original version is still in the repository for those who might prefer it.
    The carrier now prints in two pieces, and you have the option of either soldering wires directly to the switch as before, or using a 3 pin JST-XH plug in the back of the carrier.
    It turns out that the spacing of pins 1 and 3 in the JST-XH exactly line up with the "common" and "normally-open" pins on the switch, and the carrier has the correct shape for the keyed connector to plug in.
    [microswitch-v2-20-0-14.scad, microswitch-v2-5-20-14.scad, microswitch-v2-5-5-14.scad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]
2025-02-16 Disabling the USB plug by default for now. I hadn't done a full test print yet, and when I did I found that the placement interferes with the front sensor wires. Also, the breakout board doesn't seem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
    [trackball-hollow.scad]
2025-02-21 Minor fixes to microswitch-v2: - Body is slightly smaller in one dimension, for easier fit - Fixed the hinge not printing the first couple layers.
    [microswitch-v2.scad]
2025-02-27 Updates to the main shell: - reduced the size of the access cutouts for the sensor screws a bit (from 5mm to 3mm diameter -- should be plenty of room for a 1.5mm allen wrench for the M2 screws) - the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
    [test.scad, trackball-hollow.scad, trackball.scad]
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
